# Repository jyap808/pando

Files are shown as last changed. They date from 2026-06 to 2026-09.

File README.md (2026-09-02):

# Pando Keyboard

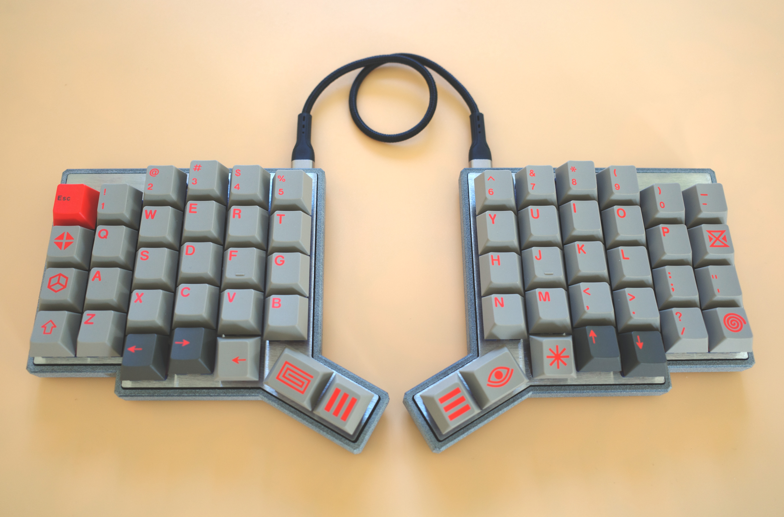
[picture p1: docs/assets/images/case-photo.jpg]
Pando case


Pando is a wired 58-key column-staggered split keyboard. It uses an integrated MCU design on the STM32 platform (STM32G0B1) with an IO expander (PCA9555) on the secondary half, connected over USB-C.

> [!NOTE]
> 📘 The **[Documentation pages](https://jyap808.github.io/pando)** contain a Build and Firmware guide.

> [!TIP]
> 🚀 Want one? Pre-assembled and PCB-tested kits are available on [Etsy](https://www.etsy.com/listing/4567044197/). Your support helps me keep this project open-source and encourages the development of new models!




## Features

- STM32G0B1KBT6 MCU (64 MHz Cortex-M0+, 144 KB SRAM)
- PCA9555 IO expander on the secondary half
- USB-C split communication with ESD protection on all ports
- Hotswap switch sockets
- Single-sided SMD components for hotplate soldering
- Vial firmware for keymap configuration
- Same key layout as the [Pando58](https://jyap808.github.io/pando58), but as an assembled PCB instead of a DIY kit

## Repository

| Directory | Description |
| --- | --- |
| `kicad/` | Schematics and PCB (left, right, switch plates) |
| `firmware/` | QMK/Vial keyboard definition |
| `ergogen/` | Layout configuration and case/plate generation |
| `case/` | 3D printed case models (FreeCAD) |
| `docs/` | This project's documentation site (built with [Zensical](https://zensical.org/)) |

## Firmware

Pando runs [Vial](https://get.vial.today/) firmware. Precompiled builds are on [GitHub Releases](https://github.com/jyap808/pando/releases) — flash with `dfu-util`, or build from source with the keyboard definition in `firmware/keyboards/`. See [Installing Firmware](https://jyap808.github.io/pando/firmware/installing-firmware/) for details.

## License

[Pando Keyboard](https://github.com/jyap808/pando) © 2026 by [Julian Yap](https://julianyap.com/) is Open Hardware, licensed under [CERN-OHL-S v2](https://ohwr.org/cern_ohl_s_v2.txt). See [LICENSE](LICENSE).

The firmware in `firmware/` is licensed under the [GPL v2](https://www.gnu.org/licenses/old-licenses/gpl-2.0.html).

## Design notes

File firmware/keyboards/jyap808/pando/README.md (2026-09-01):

# Pando

Split keyboard with STM32G0B1KBT6 master communicating with a PCA9555 I/O
expander slave over I2C via USB-C interconnect. Works as a full 58-key split,
or the left half can be used standalone.

## Matrix Configuration

The keyboard is a 58-key columnar split (mirroring the Pando58 layout) with a
single STM32G0B1 master driving both halves:

- **Left half**: rows B0-B2/A8-A9 and cols A7/A6/A2-A5 are scanned directly
  from the MCU GPIOs.
- **Right half**: rows and cols go through the PCA9555 over I2C. `MATRIX_ROWS`
  is 5, `MATRIX_COLS` is 12 (6 per side), with the right half occupying matrix
  cols 6-11.

See `config.h` for `MATRIX_ROW_PINS_L/R` and `MATRIX_COL_PINS_L/R`. The custom
matrix driver in `matrix.c` drives one row low at a time (GPIO on the left,
PCA9555 output on the right) and reads the columns, so both halves are scanned
without any split-transport logic.

### Standalone use

The **left half works standalone**: at init the driver probes the PCA9555 and
only touches the right half over I2C while it is present. If the expander is
disconnected mid-session, the right-half columns are cleared so no keys stick,
and the driver re-probes every 2 seconds for the right half to come back (see
`RIGHT_HALF_RETRY_MS` in `matrix.c`).

### Testing

Build and flash:
```
make jyap808/pando:vial
```

Connect with `qmk console` — the firmware initialises the PCA9555, reads its
pins to verify connectivity, and configures its ports in `matrix_init_custom()`.
Check the console output for device detection and error messages.

## I2C Configuration

The STM32G0B1 uses the I2Cv2 peripheral which requires explicit timing register
configuration via `I2C1_TIMINGR_*` defines in `config.h`.

The SCL frequency formula is:
```
f_SCL = f_I2CCLK / ((SCLL+1 + SCLH+1) * (PRESC+1))
```

### Clock source

The GENERIC_STM32_G0B1XB board config (used by QMK for STM32G0B1) sets the I2C1
clock source to PCLK (64MHz) via `STM32_I2C1SEL = STM32_I2C1SEL_PCLK`.

This keyboard does not need to override the clock source — PCLK = SYSCLK
= 64MHz.

### Timing values

QMK's ChibiOS I2C driver takes `I2C1_TIMINGR_*` defines from `config.h` and
falls back to built-in defaults (in `platforms/chibios/drivers/i2c_master.c`,
commented as "assuming a 72MHz clock") if they are not set. The values in
`config.h` are those same defaults, spelled out explicitly so the timing does
not depend on QMK's fallback values:

- `I2C1_TIMINGR_PRESC = 0`
- `I2C1_TIMINGR_SCLDEL = 7` (8 × 15.625ns = 125ns data setup, meets FM 100ns minimum)
- `I2C1_TIMINGR_SDADEL = 0`
- `I2C1_TIMINGR_SCLH = 38`
- `I2C1_TIMINGR_SCLL = 129`

At the 64MHz PCLK on this board this gives f_SCL = 64MHz / 169 ≈ 378kHz,
which is valid Fast-mode.

### Voltage notes

VBUS provides 5V to the slave side, with I2C lines pulled up to 5V
via 5kΩ resistors. PB6/PB7 are 5V tolerant (FTf) on STM32G0B1.

## License

This keyboard definition is licensed under the [GPL v2](https://www.gnu.org/licenses/old-licenses/gpl-2.0.html).

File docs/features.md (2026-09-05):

# Features

[Pando](https://github.com/jyap808/pando/) is Open Hardware, licensed under the [CERN-OHL-S v2](https://ohwr.org/cern_ohl_s_v2.txt).

- **MCU:** [STM32G0B1KBT6](https://www.st.com/en/microcontrollers-microprocessors/stm32g0b1kb.html). This is a newer MCU that offers benefits over an older, more commonly used MCU such as the STM32F072CBT6:
    - 64 MHz ARM Cortex-M0+ core, up from 48 MHz
    - 144 KB SRAM, up from 16 KB (~9x)
    - Consolidated single-supply core (VDD) with a modern power layout, reducing decoupling capacitors from 6 to 1
    - Streamlined LQFP-32 package instead of LQFP-48, keeping the same 7x7 mm body with a larger 0.875 mm pin pitch for easier soldering
    - Active ST support, keeping the design future-proof
- **IO expander:** PCA9555, communicating with the MCU over I²C
- **Split communication:** USB-C with ESD protection on all ports
- **Switches:** Hotswap sockets
- **Assembly:** Single-sided SMD components for hotplate soldering

The project uses [Ergogen](https://github.com/ergogen/ergogen) for layout generation and [KiCad](https://www.kicad.org/) for schematic/PCB design.

## Layout Template

Print out this [1:1 letter-size template](assets/pando-layout.pdf) and test the layout.

<iframe src="assets/pando-layout.pdf" width="100%" height="800px" style="border: 1px solid rgba(0,0,0,0.2); border-radius: 4px;"></iframe>

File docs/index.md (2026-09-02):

# Pando Keyboard

Pando case

Pando is a wired 58 key column-staggered split keyboard.

It uses an integrated MCU design on the STM32 platform with an IO expander on the secondary half of the keyboard.

Pando utilizes the same key layout as the [Pando58](https://jyap808.github.io/pando58). The core difference is that the Pando58 keyboard was designed as a DIY kit (with external controllers) while Pando is designed as an assembled PCB. This allows for a cleaner and more cohesive design.

!!! tip "Buy Pando"
    Pando comes as a pre-assembled kit on [Etsy](https://www.etsy.com/listing/4567044197/). Just provide your own keycaps and switches. Your support helps me keep this project open-source and encourages the development of new models!

## Getting Started

Visit the [Build page](build/) to learn about the assembly process.

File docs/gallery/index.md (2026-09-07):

# Gallery

Here are some examples to inspire your build.

A more extensive gallery of keycap options can be found in the [Pando58 Gallery](https://jyap808.github.io/pando58/gallery).

## MJF Case

Here is the Multi-Jet Fusion (MJF) printed case, printed in PA12-HP Nylon in natural grey. It features a stainless steel switch plate and bottom plate.

This MJF case suits my design ethos — simple, functional, minimal, true to its materials. Inspired by Brutalist architecture, MJF substitutes for concrete in its raw unfinished grey tone, with stainless steel peeking out from top and bottom.

Keycaps are Keykobo Signet. I prefer sets with icon modifiers since I flip the 3 inner thumb keys upside-down for a more natural feel. For backspace, I use a flipped right arrow key.

MJF Case - Top view with USB-C interconnect cable

Top view with USB-C interconnect cable.

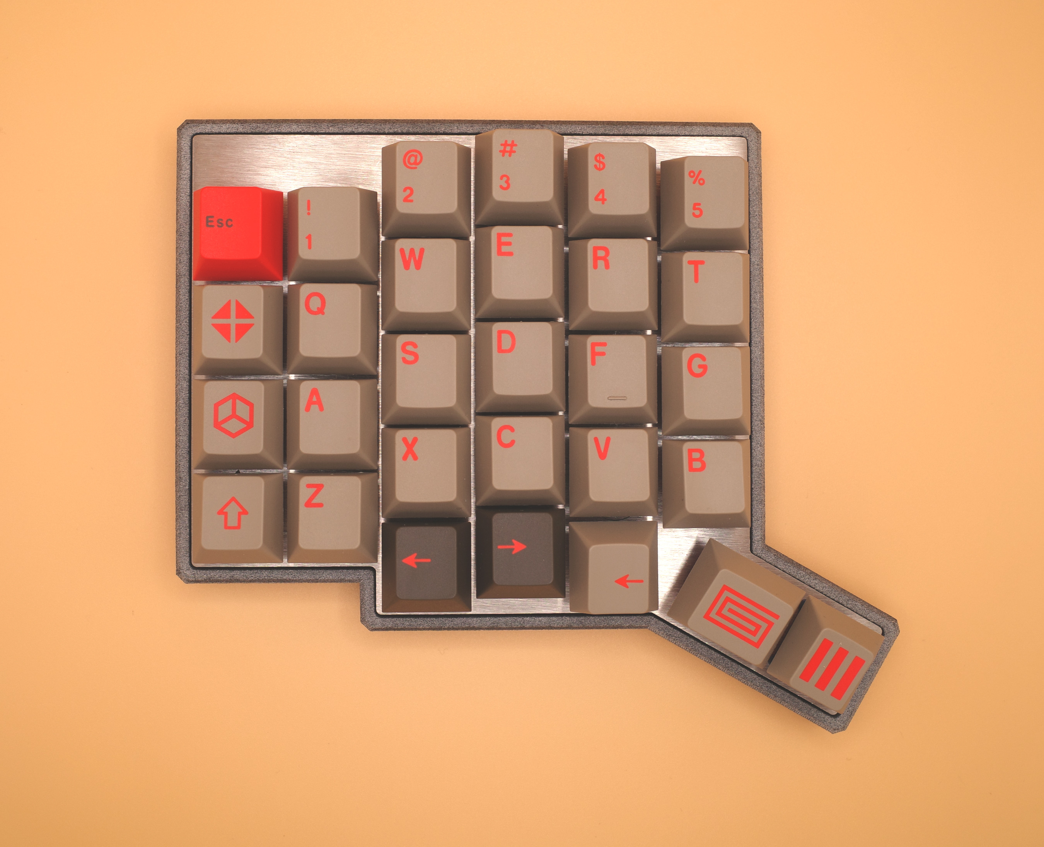
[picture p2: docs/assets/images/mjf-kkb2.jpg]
MJF Case - Left half top view


Left half top view.

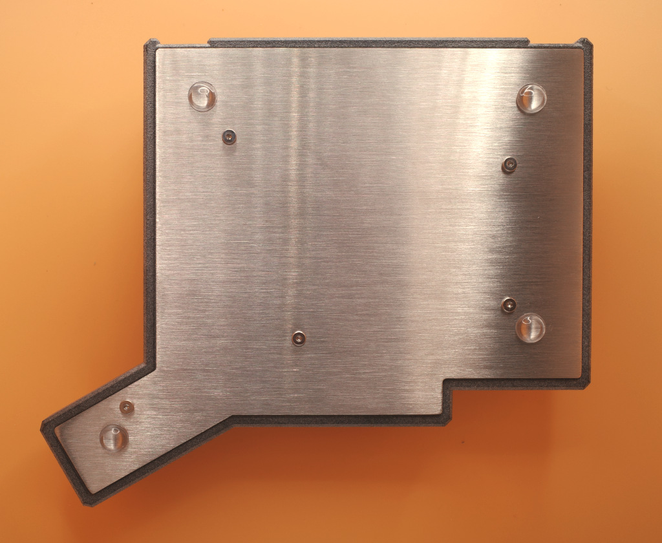
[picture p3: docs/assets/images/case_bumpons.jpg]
MJF Case - Left half, bottom view with the stainless steel plate


Left half, bottom view with the stainless steel plate.

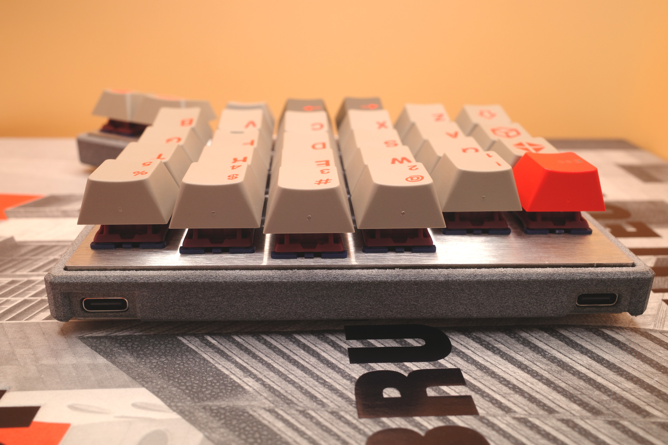
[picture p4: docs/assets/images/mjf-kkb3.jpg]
MJF Case - Left half, view from the back


Left half, view from the back.

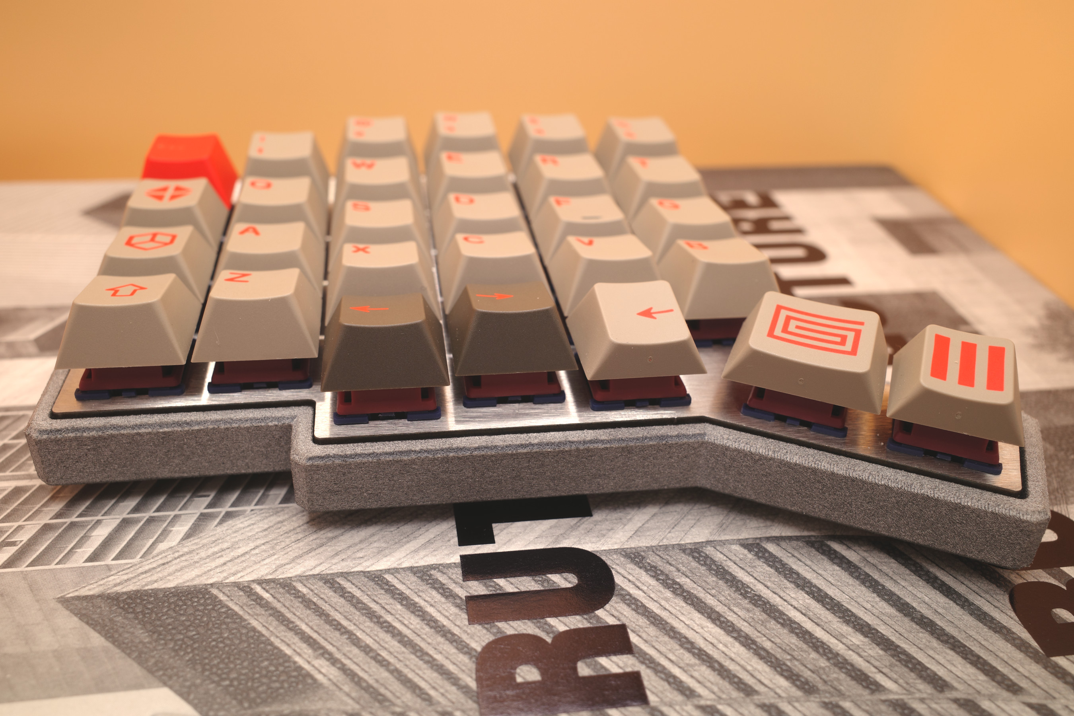
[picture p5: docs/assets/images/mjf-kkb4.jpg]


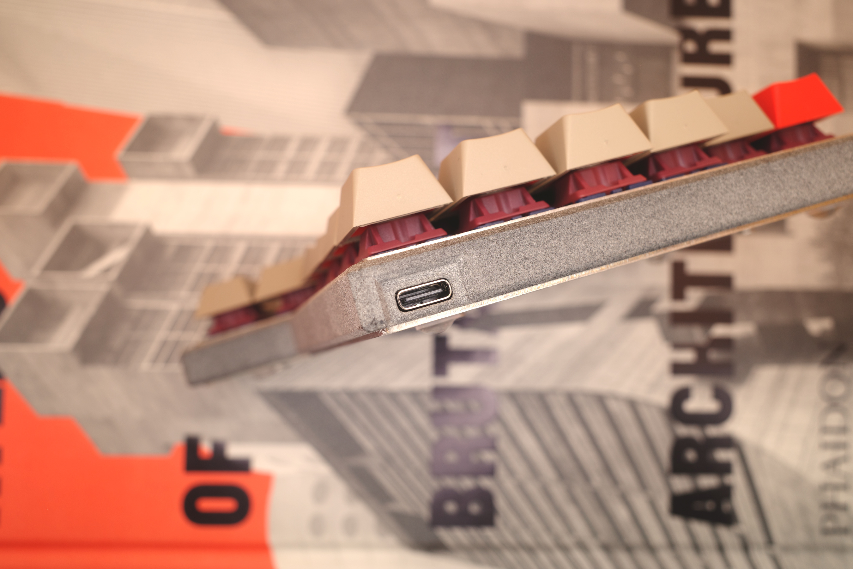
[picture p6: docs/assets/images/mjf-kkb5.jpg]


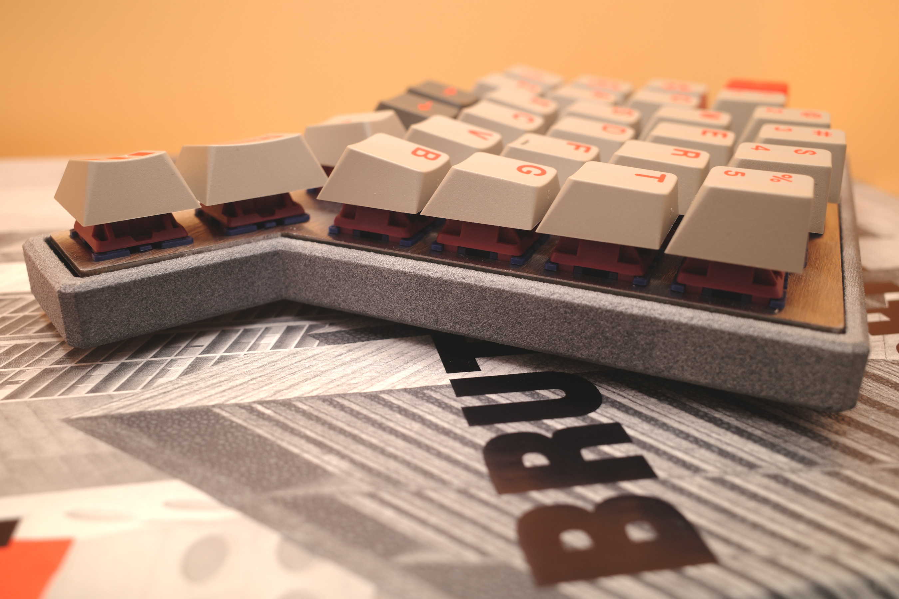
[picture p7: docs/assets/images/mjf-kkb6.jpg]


## 3D Printed Case

Here is the 3D printed case, printed in black Ambrosia ASA filament. It features a FR4 switch plate in black. Keycaps are GMK Dots. I am a fan of keycap sets where the modifiers are minimal icons.

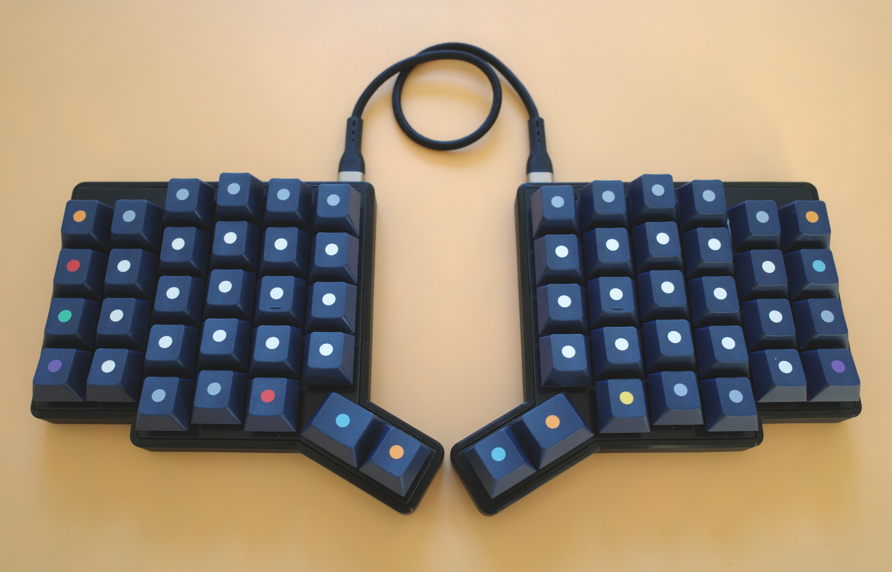
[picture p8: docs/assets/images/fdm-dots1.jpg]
3D Printed Case - Top view with USB-C interconnect cable


Top view with USB-C interconnect cable.

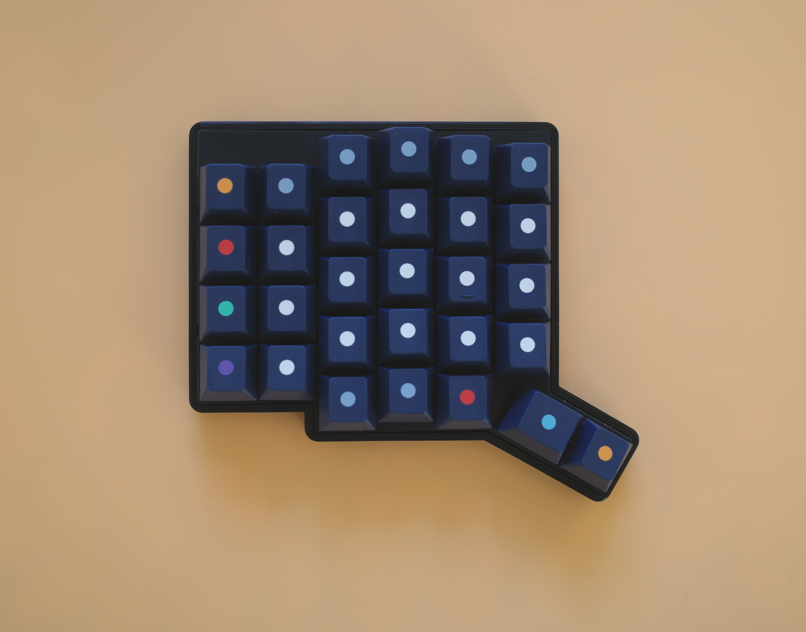
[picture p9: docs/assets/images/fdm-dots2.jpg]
3D Printed Case - Left half top view


Left half top view.

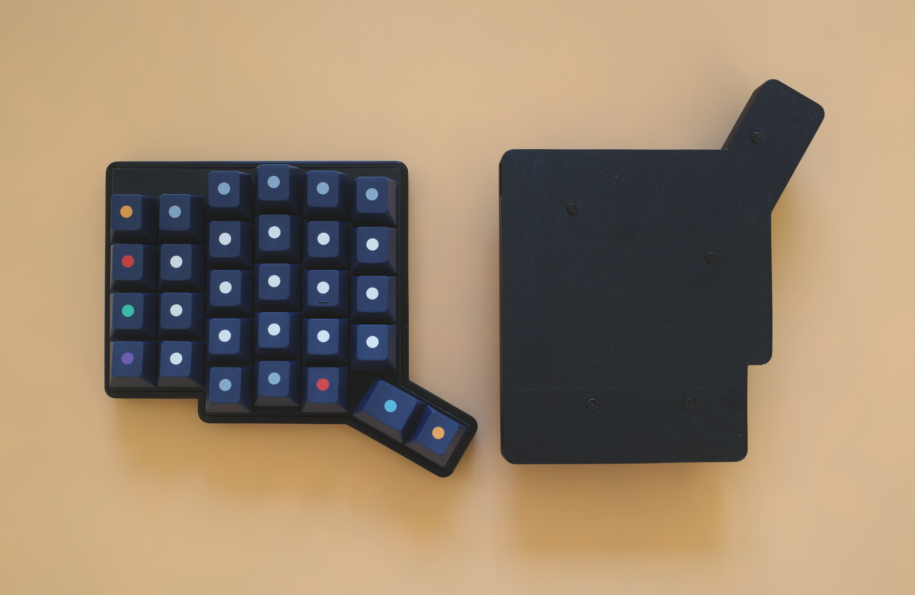
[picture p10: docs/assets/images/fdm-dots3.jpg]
3D Printed Case - Left half top view and right half bottom view


Left half top view and right half bottom view.

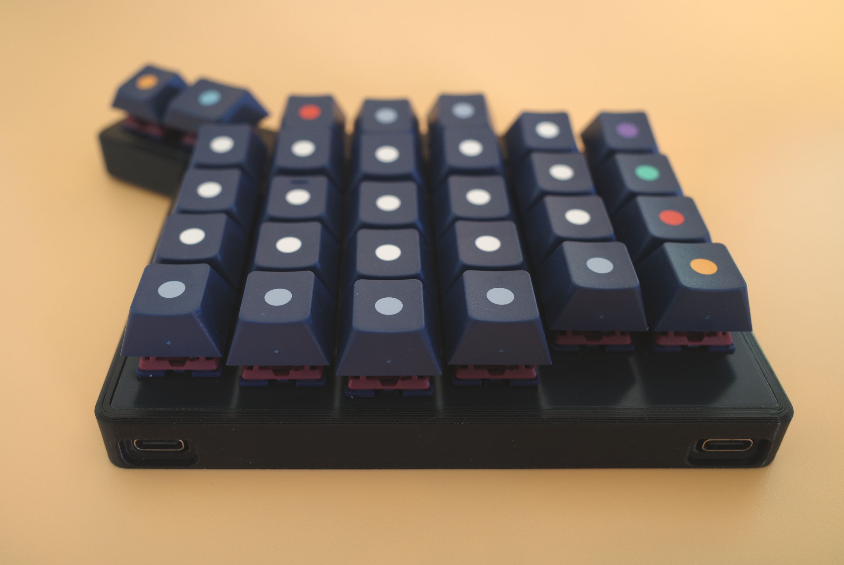
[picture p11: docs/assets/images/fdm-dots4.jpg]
3D Printed Case - Left half, view from the back


Left half, view from the back.

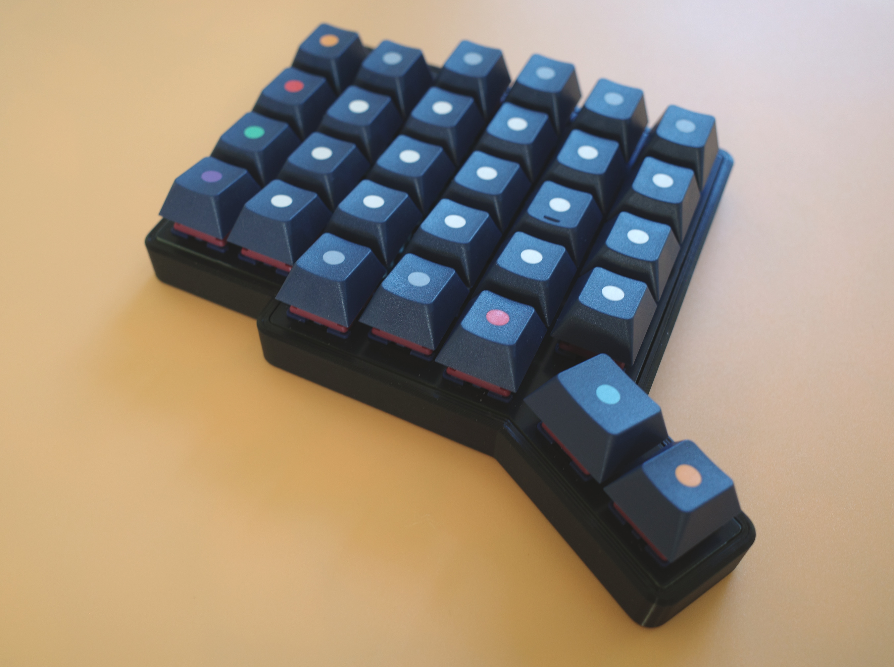
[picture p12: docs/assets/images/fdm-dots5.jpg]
3D Printed Case - Left half, angled view


Left half, angled view.

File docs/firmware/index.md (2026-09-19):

# Firmware and Configuration

Pando uses Vial firmware. Once installed, [Vial](https://get.vial.today/) (the application) is used to configure the keyboard.

!!! note
    Pre-built keyboards from my [Etsy Store](https://www.etsy.com/listing/4567044197/) arrive pre-flashed with firmware and fully PCB-tested, ready to use out of the box.

To flash the keyboard yourself, see [Installing Firmware](installing-firmware.md).

## Getting Vial

Download Vial (the desktop application) from the [official website](https://get.vial.today/) for your platform.

Alternatively, you can use [Vial Web](https://vial.rocks) in your browser — no download required.

## Configuring with Vial

Open [Vial](https://get.vial.today/) to configure the keyboard. The Pando should connect automatically when the firmware is installed.

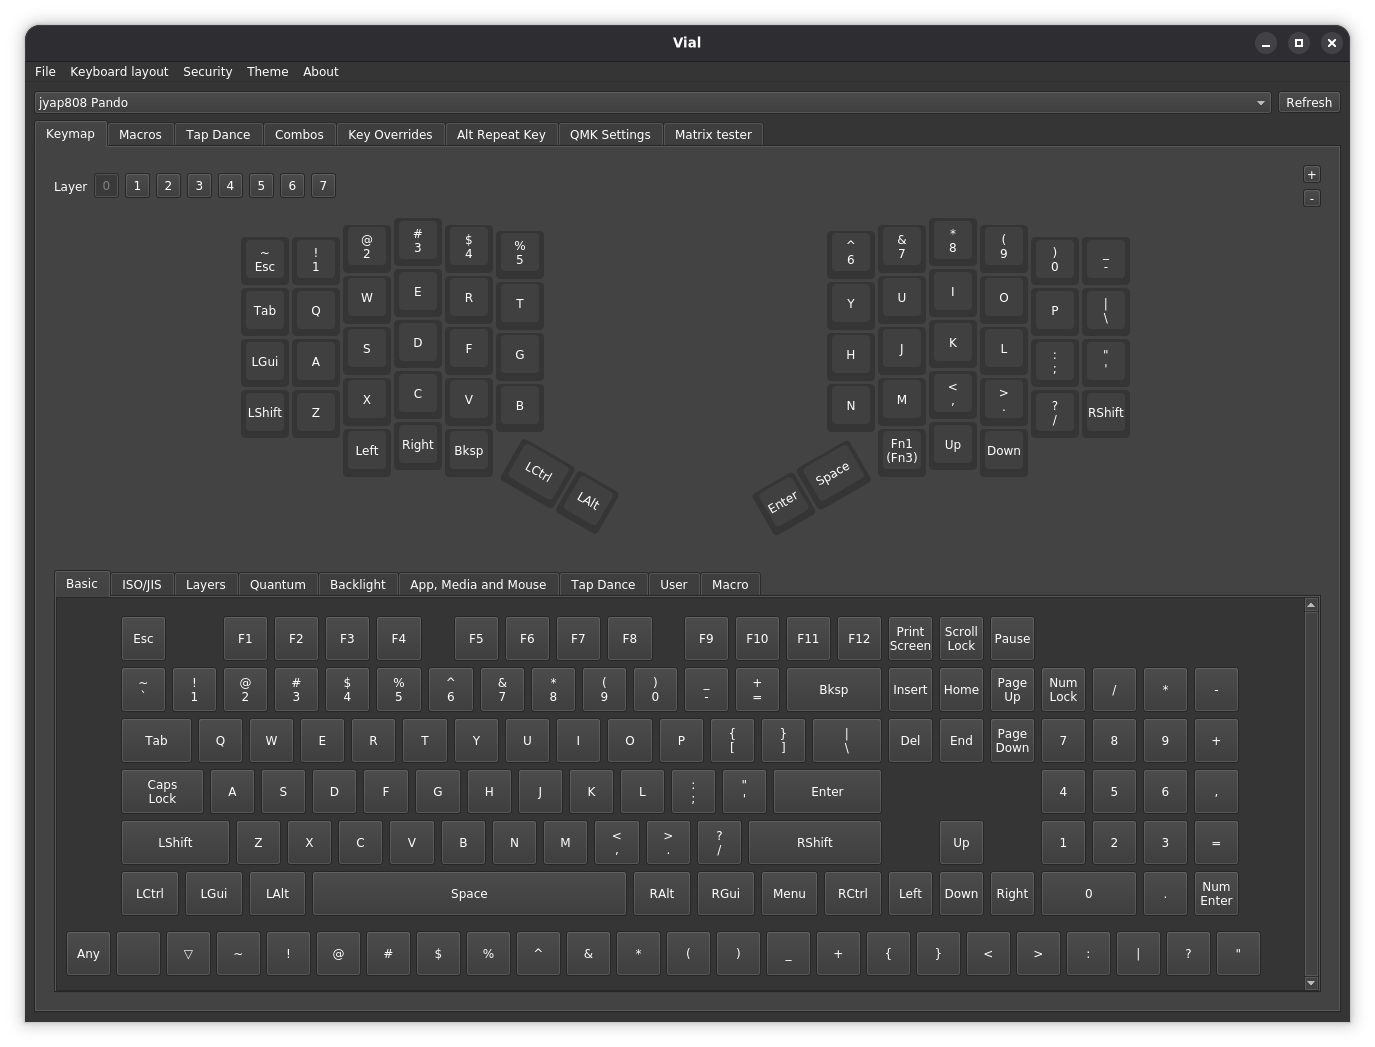
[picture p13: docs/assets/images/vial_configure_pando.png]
Vial application showing Pando keyboard configuration


Vial allows you to remap keys, create layers, and configure macros for your Pando keyboard.

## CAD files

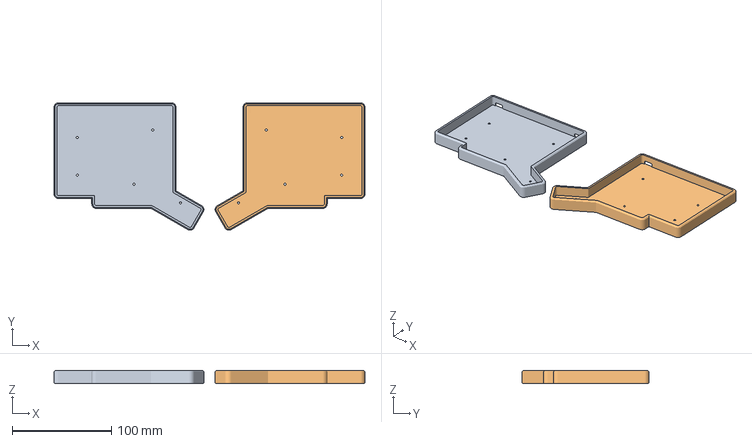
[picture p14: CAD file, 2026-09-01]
case/PandoCase.FCStd
313.1 x 128.3 x 12.6 mm
Pando FDM Left (Meshed)
Pando FDM Right (Meshed)

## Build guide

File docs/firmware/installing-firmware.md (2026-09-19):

# Installing Firmware

!!! note
    Pando is a split keyboard with an MCU on the master half only. The secondary half uses an I/O expander over I2C, so only the master MCU needs to be flashed.

There are two ways to get the latest Vial firmware for Pando:

1. **Precompiled firmware** — Download precompiled firmware from [GitHub Releases](https://github.com/jyap808/pando/releases) and flash via `dfu-util` (simplest option).
2. **Manual build method** — Clone the vial-qmk repo, build locally, and flash via CLI.

## Prerequisites: Enable the Boot Button (Legacy Boot Mode)

!!! note
    This step is not required for pre-built keyboards from my [Etsy Store](https://www.etsy.com/listing/4567044197/) as it has already been completed.

The STM32G0 series handles booting differently from older STM32 parts. Booting is controlled by a software configuration bit called `nBOOT_SEL` in the Option Bytes rather than purely by hardware.

By default, `nBOOT_SEL` is set to `1`, which tells the MCU to **ignore the physical BOOT0 pin** entirely. Instead it uses an **Empty Check** mechanism: a blank chip automatically enters DFU mode, but once code is flashed, it always boots straight into your firmware — ignoring BOOT0 even if it's held HIGH.

### Why?

The BOOT0 pin on the G0 is multiplexed with GPIOs and programming lines (e.g. SWCLK on PA14). Disabling it by default lets designers use that pin as a regular I/O without risking accidental bootloader entry.

### Enabling Legacy Boot Behavior

To restore hardware BOOT0 control (so a physical button can force DFU mode at any time), clear the `nBOOT_SEL` bit. This can be done via the GUI or the CLI, both using the [STM32CubeProgrammer](https://www.st.com/en/development-tools/stm32cubeprog.html) tool.

**GUI method:** Open STM32CubeProgrammer → Option Bytes → User Configuration, uncheck `nBOOT_SEL`, and apply.

**CLI method:** Use `STM32_Programmer_CLI` to list devices, display option bytes, and set the bit.

First, list available DFU devices:

    $ STM32_Programmer_CLI -l

    =====  DFU Interface   =====

    Total number of available STM32 device in DFU mode: 1

      Device Index           : USB1
      Product ID             : DFU in FS Mode
      Device ID              : 0x0467

Display current option bytes (factory default shows `nBOOT_SEL : 0x1`):

    $ STM32_Programmer_CLI -c port=usb1 -ob displ

      User Configuration:

         nBOOT_SEL    : 0x1 (BOOT0 signal is defined by nBOOT0 option bit)

Clear `nBOOT_SEL` to enable legacy boot pin behavior:

    $ STM32_Programmer_CLI -c port=usb1 -ob nBOOT_SEL=0

    OPTION BYTE PROGRAMMING VERIFICATION:

    Option Bytes successfully programmed

Confirm the change (`nBOOT_SEL` now shows `0x0`):

    $ STM32_Programmer_CLI -c port=usb1 -ob displ

      User Configuration:

         nBOOT_SEL    : 0x0 (BOOT0 signal is defined by BOOT0 pin value (legacy mode))

### Recommended Setup Sequence

Clear the option byte on a fresh chip **before** flashing firmware. This ensures the BOOT0 pin is active even if your first firmware build has a catastrophic bug, guaranteeing you can always recover via DFU:

**Brand New MCU** → **Clear nBOOT_SEL** → **Test Bootloader** → **Flash Firmware**

## Precompiled Method: Download from Releases + `dfu-util`

1. Go to the [Releases page](https://github.com/jyap808/pando/releases)

2. Download the latest firmware file (e.g. `jyap808_pando_vial.bin`)

3. Put the keyboard into DFU mode by holding the boot/reset button on the MCU while plugging in the USBC cable.

4. Flash the firmware with `dfu-util`:

        dfu-util -d 0483:df11 -a 0 -s 0x08000000:leave -D jyap808_pando_vial.bin

    The device should show up as an STM32 BOOTLOADER. On Linux you may need `sudo` or a udev rule for the DFU device.

    A quick breakdown of the `dfu-util` flags:

    - `-d 0483:df11` — the USB VID:PID of ST's STM32 bootloader, which all STM32-system-DFU devices enumerate as.
    - `-a 0` — select alternate 0, the internal flash media. This is the same alternate QMK uses when flashing `stm32-dfu` boards.
    - `-s 0x08000000:leave` — program at `0x08000000`, the standard STM32G0 flash base address, then `leave` to jump to the application on completion.

5. The keyboard will reboot with the new firmware

## Manual Build Method: CLI Build + Flash (Advanced)

1. Clone the official Vial QMK fork:

        git clone https://github.com/vial-kb/vial-qmk.git
        cd vial-qmk

2. Initialize submodules (important for QMK dependencies):

        make git-submodule

3. Clone or download the Pando keyboard folder from the [GitHub repo](https://github.com/jyap808/pando).

    Copy the entire `firmware/keyboards/jyap808/pando/` folder into `vial-qmk/keyboards/jyap808/pando/`.

4. Compile the Vial firmware:

        make jyap808/pando:vial

5. Flash using the CLI.

    For an STM32 target this uses USB DFU. You can use QMK's wrapper, which runs `dfu-util` under the hood:

        qmk flash jyap808/pando:vial

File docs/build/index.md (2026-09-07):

# Assembly

## Overview

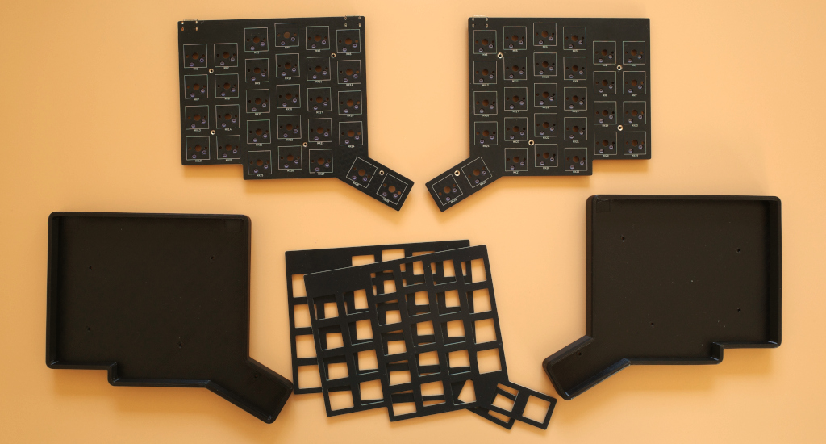
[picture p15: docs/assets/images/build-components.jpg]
Build components


This guide covers the **3D-printed case** build using the 2 PCBs, 2 reversible switch plates and 2 3D-printed cases.

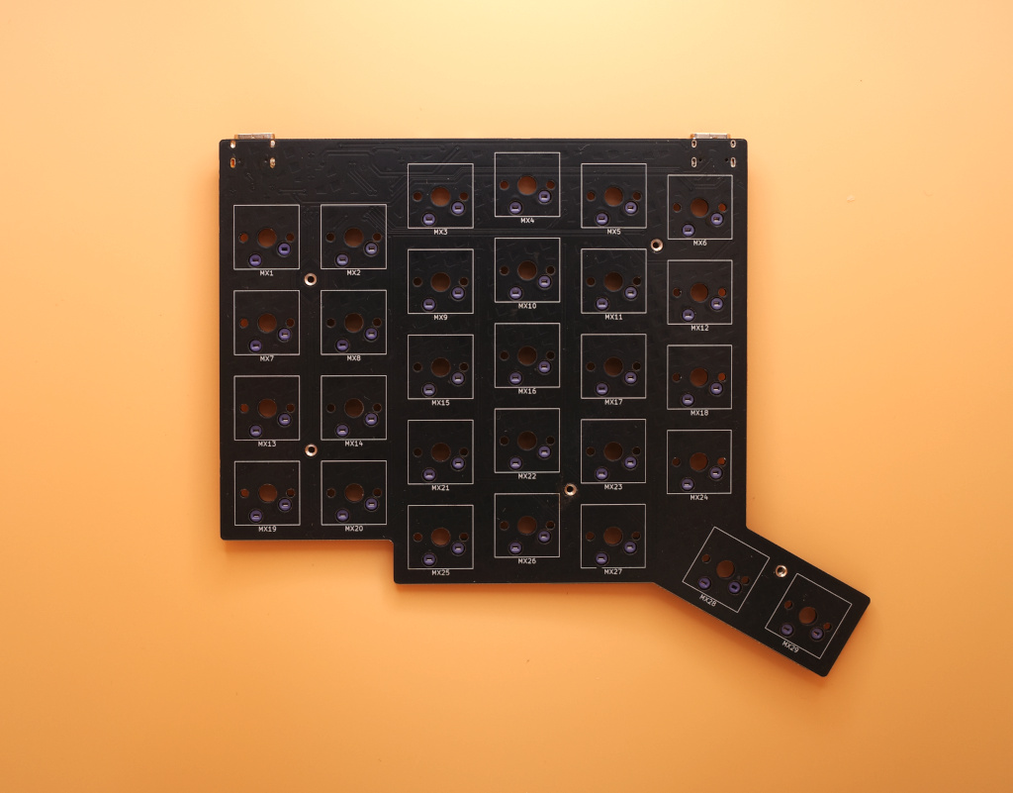
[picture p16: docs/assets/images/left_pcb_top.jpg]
Left PCB top


This guide walks through assembling **one half** (the Left half) of the PCBs since the assembly is identical on both halves. Pictured above is the Left PCB top side.

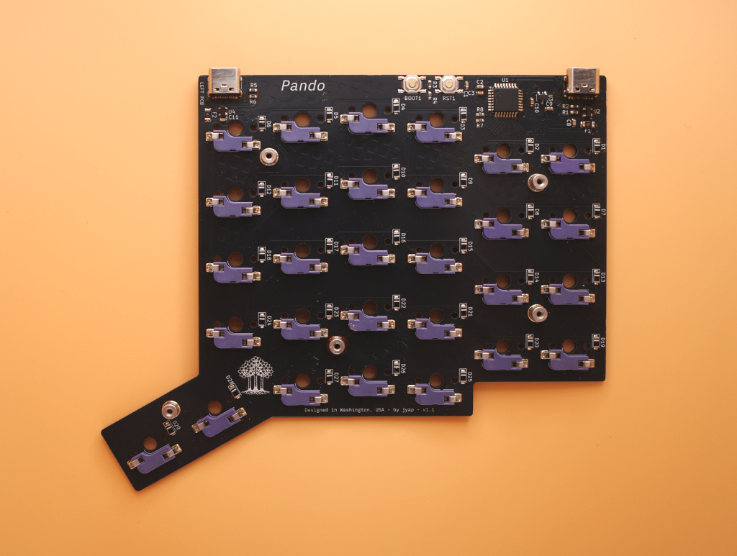
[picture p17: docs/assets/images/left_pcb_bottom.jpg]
Left PCB bottom


Left PCB bottom side, ready to be assembled. The Left PCB has more components and 2 USB-C ports. In the top left, you can see it says "Left PCB". In this view, the top Left USB-C port is the interconnect port (connects to the Right side PCB) and the Right USB-C port is the main port which connects to the PC.

## Assembly Steps

### Switches - Switch and Plate Installation

The switches are installed between the switch plate and the PCB.

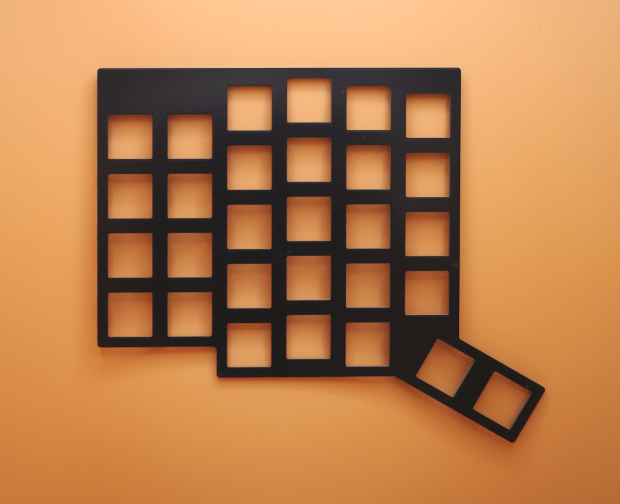
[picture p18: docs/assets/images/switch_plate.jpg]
Switch plate


The switch plate is reversible and works for both Left and Right halves.

#### Installing Switches on the Plate

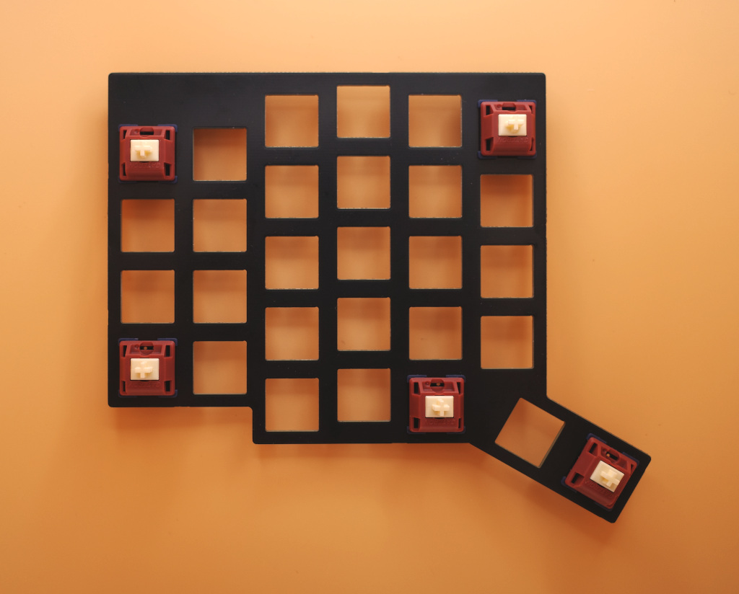
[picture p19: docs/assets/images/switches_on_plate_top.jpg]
Switches on Plate - Top


Insert guide switches into the plate. These are initial switches used to align the plate with the PCB before inserting the rest of the switches.

Place switches on the edges for structural support. Use the same 5 positions pictured.

The switch pins must face **down** (towards the bottom of the plate) to align with the hotswap sockets.

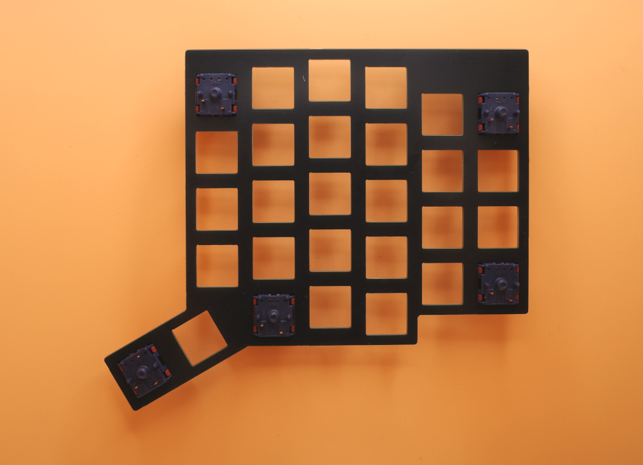
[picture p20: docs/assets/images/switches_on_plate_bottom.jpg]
Switches on Plate - Bottom


#### Attaching Switches to PCB

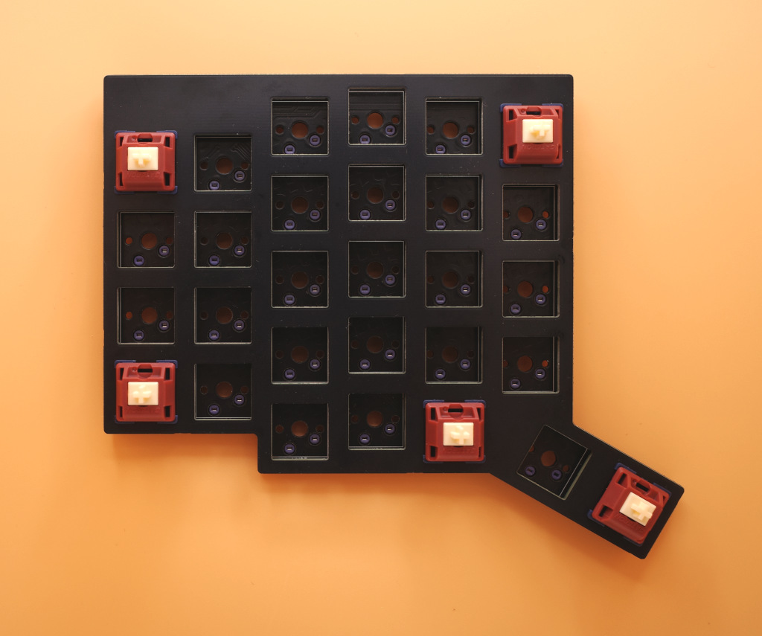
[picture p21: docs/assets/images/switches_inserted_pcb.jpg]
Switches Inserted into PCB


Place the switch plate onto the PCB. Fully press the switches into the hotswap sockets. When inserting the switches, press on the back of the socket to prevent excess pressure on it from the pins.

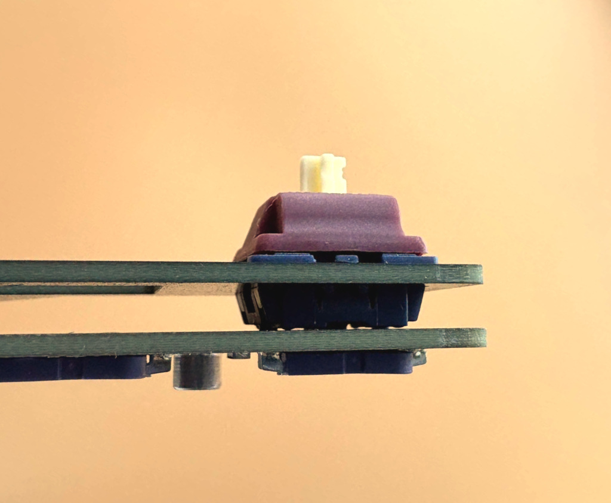
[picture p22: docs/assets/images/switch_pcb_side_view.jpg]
Switch PCB Side View


The image above shows a switch sitting flush against the PCB.

Insert the remaining switches into the PCB.

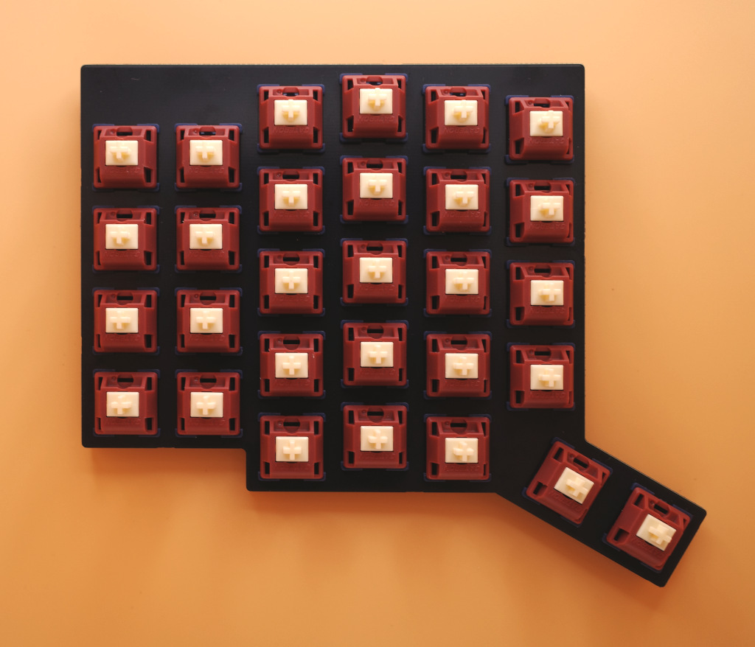
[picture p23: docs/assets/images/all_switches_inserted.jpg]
All Switches Inserted


The above image shows all 29 switches inserted into the plate for one half of the keyboard.

### Case

#### Insert PCB into Case

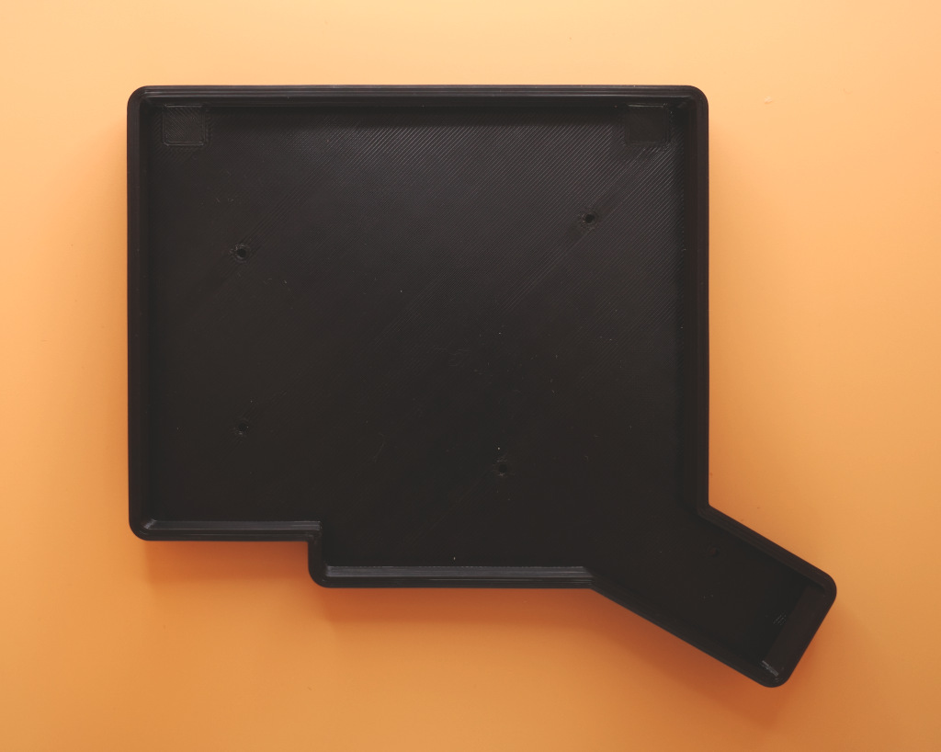
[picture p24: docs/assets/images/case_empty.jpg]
Empty case


The USB-C ports on the PCB must slot into the back of the case first! The Left half has 2 USB-C ports and the Right half has 1 USB-C port.

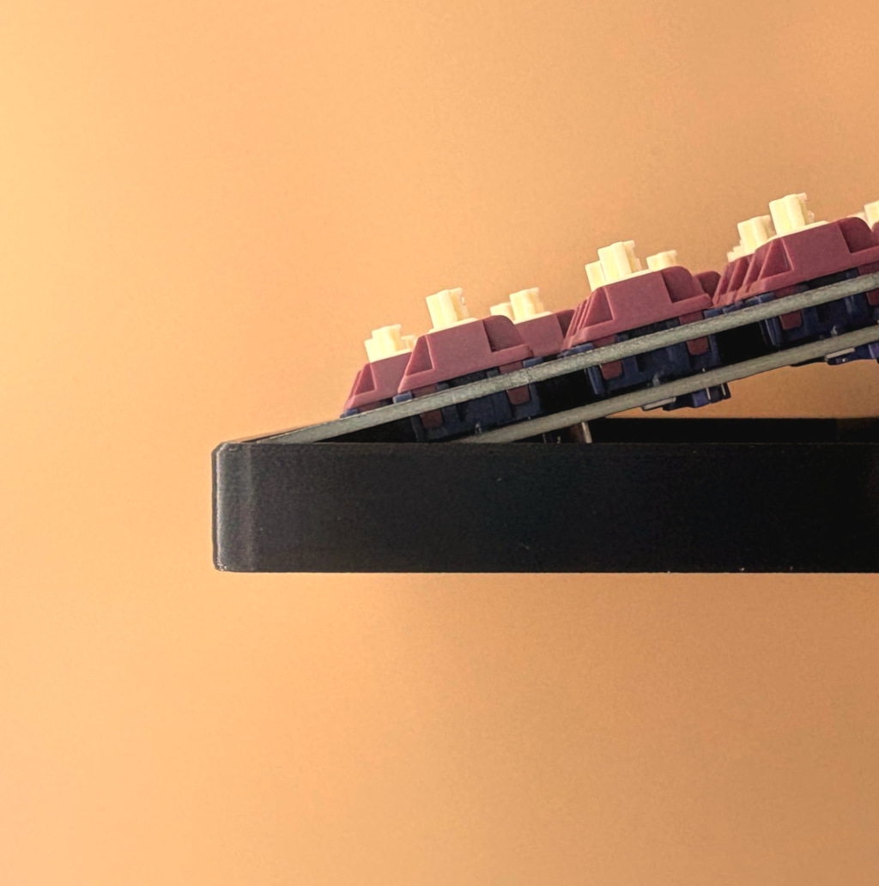
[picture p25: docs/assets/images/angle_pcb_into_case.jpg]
Angle PCB into case


Angle the PCB and populated switch plate downwards and into the case so that the USB-C ports slide into the case openings.

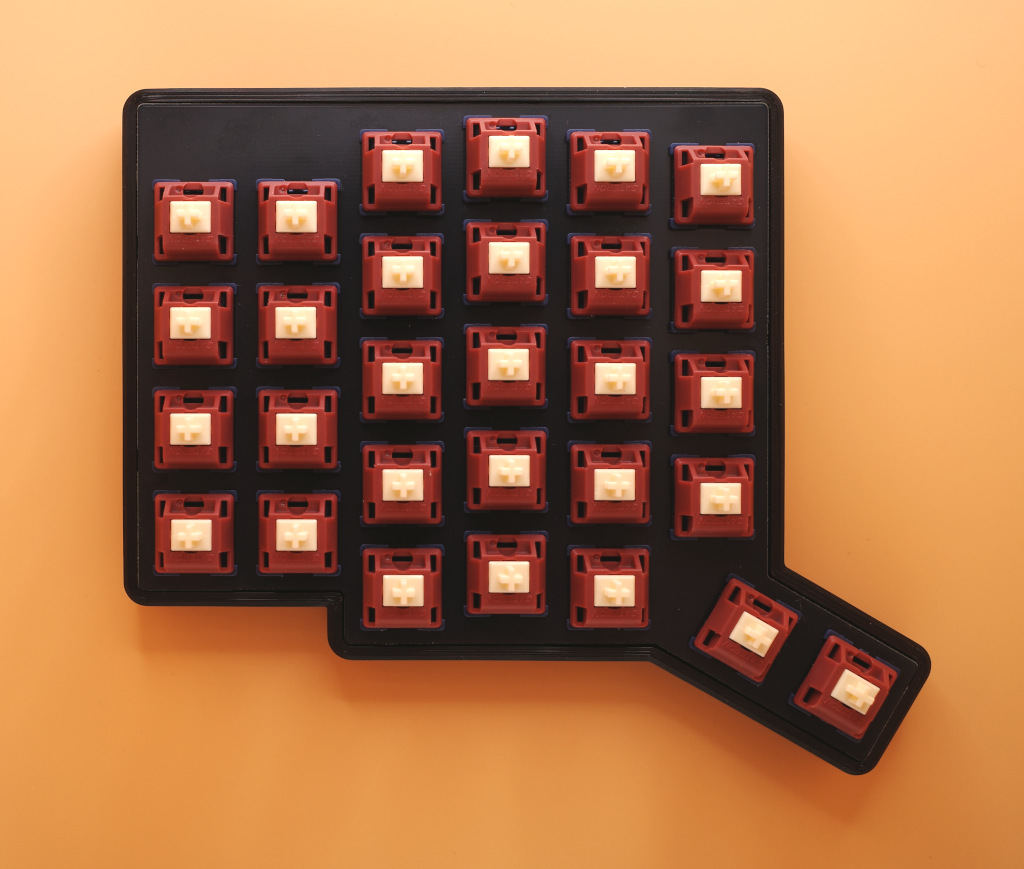
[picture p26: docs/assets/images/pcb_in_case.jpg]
PCB in case


The front side can then slot into the case. When disassembling, reverse this and take the front out first.

#### Screw the PCB into the Case

Screw the 5 screws into the case on the bottom.

Do not over-tighten the screws as you don't want to damage the standoffs attached to the PCB.

### Keycaps and Optional Bumpons

#### Keycaps

Add keycaps to the switches.

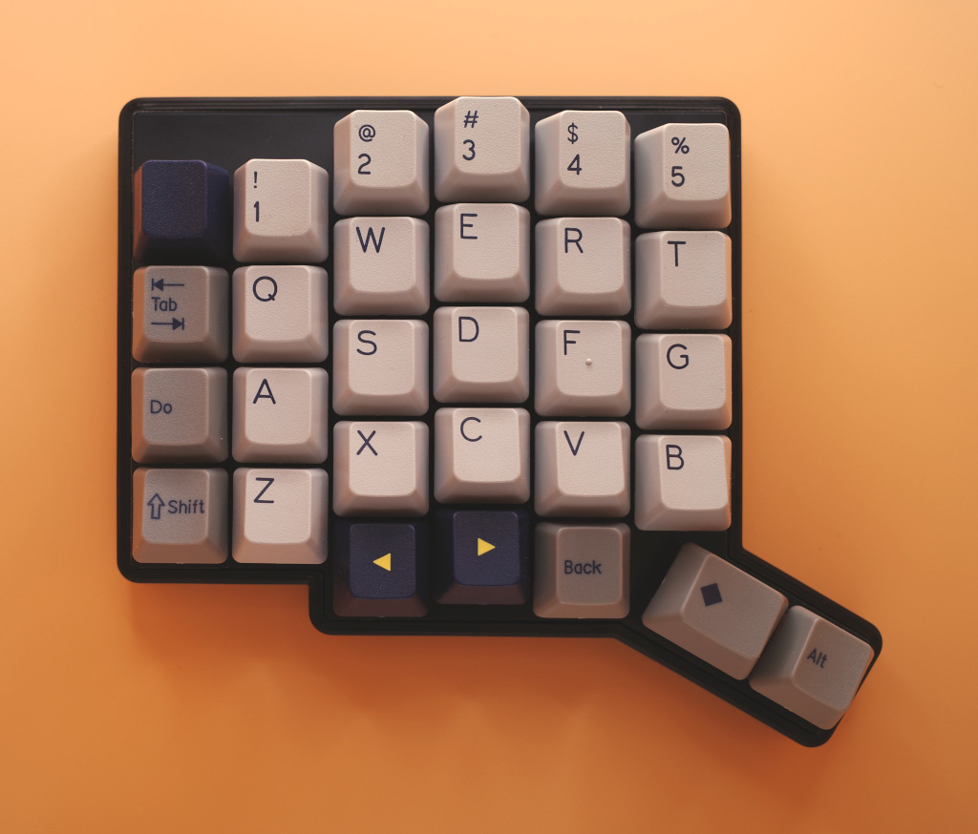
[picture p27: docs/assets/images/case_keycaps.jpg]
Case with keycaps


You can add keycaps to suit the layout that you deem optimal. This may come through some experimentation with layouts that you can configure through [Vial](../firmware/).

One of the thumb keys is designed to take a 1.25U key but you can also use a 1U key.

More Pando build examples can be found in the [Gallery](../gallery/).

A more extensive gallery of keycap options can be found in the [Pando58 Gallery](https://jyap808.github.io/pando58/gallery).

#### Bumpons

Optionally add the Bumpons to the bottom of the case.

Case with bumpons

Add 4 Bumpons per side in the configuration shown.

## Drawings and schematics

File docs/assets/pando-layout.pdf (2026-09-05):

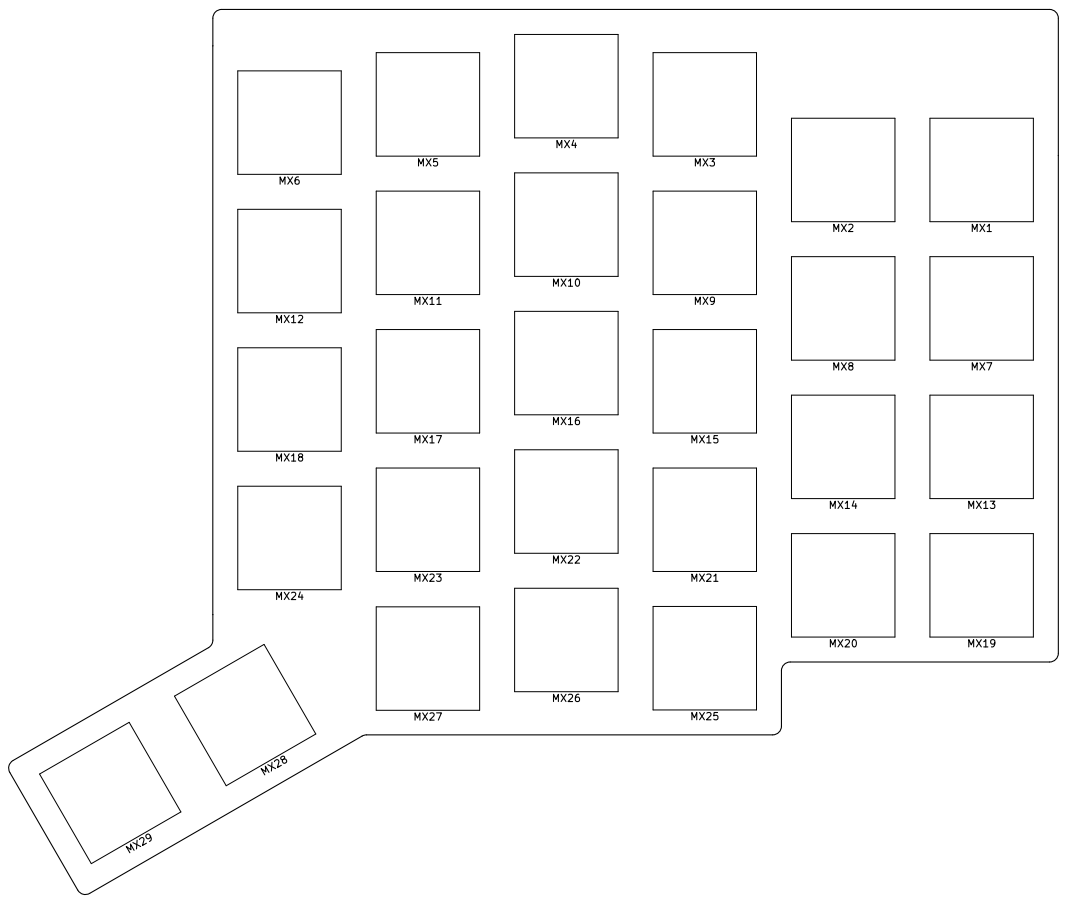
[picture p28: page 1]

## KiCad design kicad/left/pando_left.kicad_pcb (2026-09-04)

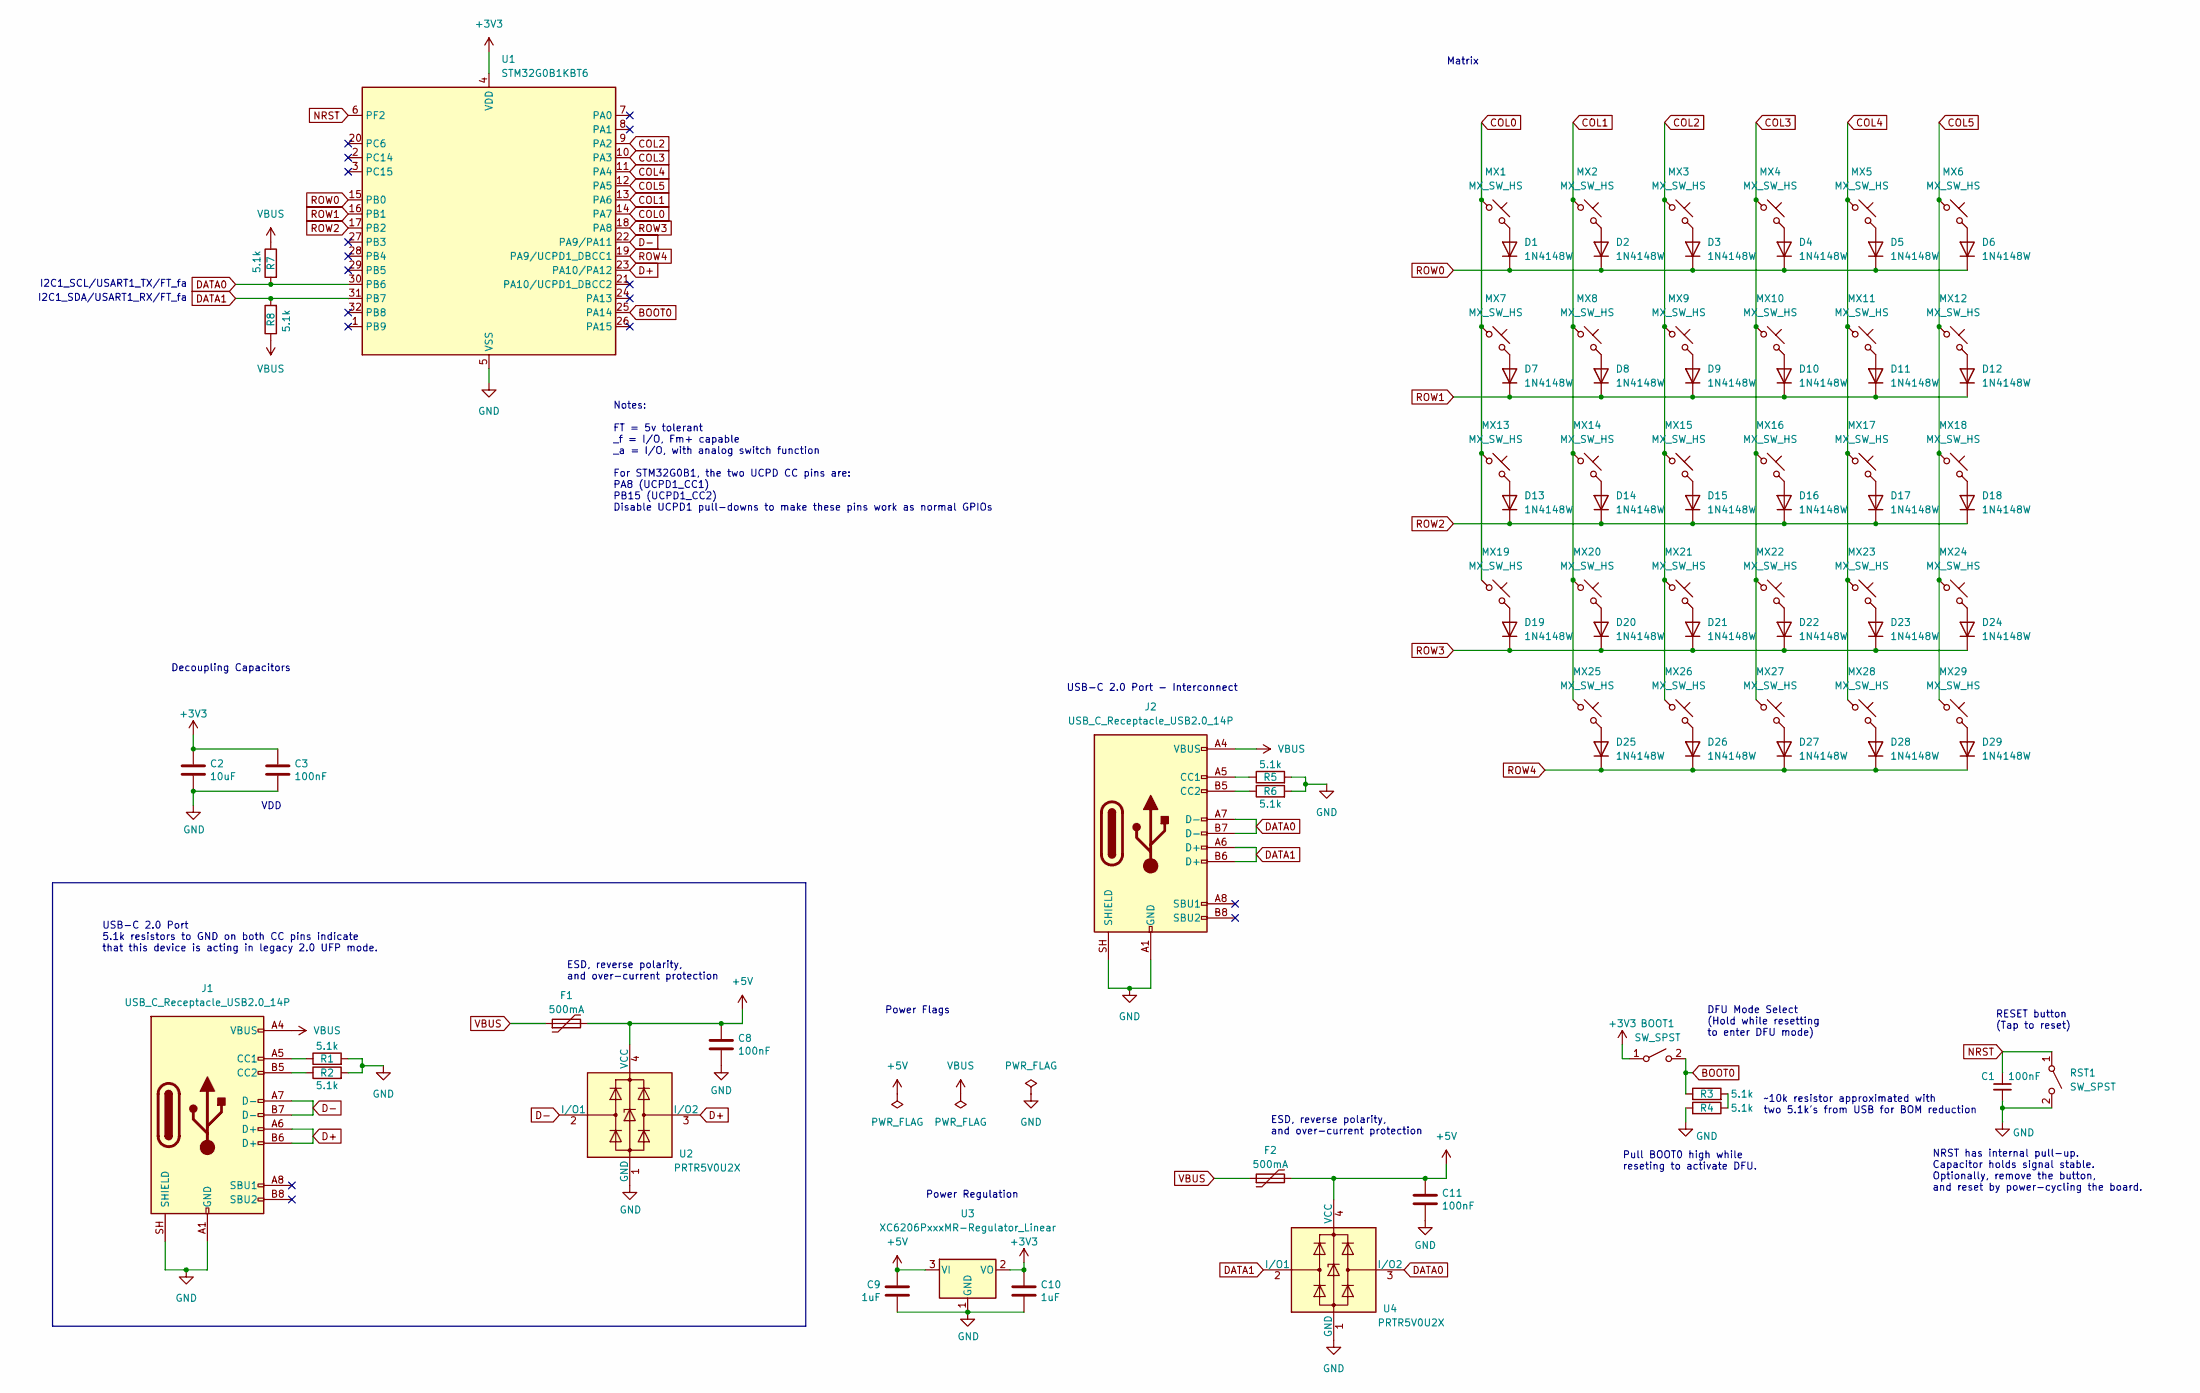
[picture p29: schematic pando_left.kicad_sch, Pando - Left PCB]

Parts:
BOOT1: SW_SPST; SW_SPST_TL3342; LCSC C318884
C1, C3, C8, C11: 100nF; C_0603_1608Metric; LCSC C14663
C2: 10uF; C_0603_1608Metric; LCSC C19702
C9, C10: 1uF; C_0603_1608Metric; LCSC C15849
D1, D2, D3, D4, D5, D6, D7, D8, D9, D10, D11, D12, D13, D14, D15, D16, D17, D18, D19, D20, D21, D22, D23, D24, D25, D26, D27, D28, D29: 1N4148W; D_SOD-123; LCSC C81598
F1, F2: 500mA; Fuse_1206_3216Metric; LCSC C135341
J1, J2: USB_C_Receptacle_USB2.0_14P; USB_C_Receptacle_HRO_TYPE-C-31-M-12; LCSC C165948
MX1, MX2, MX3, MX4, MX5, MX6, MX7, MX8, MX9, MX10, MX11, MX12, MX13, MX14, MX15, MX16, MX17, MX18, MX19, MX20, MX21, MX22, MX23, MX24, MX25, MX26, MX27, MX28, MX29: MX_SW_HS; SW_Hotswap_Kailh_MX; LCSC C41430893
R1, R2, R3, R4, R5, R6, R7, R8: 5.1k; R_0603_1608Metric; LCSC C2907114
RST1: SW_SPST; SW_SPST_TL3342; LCSC C318884
U1: STM32G0B1KBT6; LQFP-32_7x7mm_P0.8mm
U2, U4: PRTR5V0U2X; SOT-143; LCSC C2827688
U3: XC6206PxxxMR-Regulator_Linear; SOT-23-3; LCSC C5446

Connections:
+3V3: BOOT1.1 (A), C2.1, C3.1, C10.1, U1.4 (VDD), U3.2 (VO)
+5V: C8.1, C9.1, C11.1, F1.2, F2.2, U2.4 (VCC), U3.3 (VI), U4.4 (VCC)
BOOT0: BOOT1.2 (B), R3.1, U1.25 (PA14)
COL0: MX1.1, MX7.1, MX13.1, MX19.1, U1.14 (PA7)
COL1: MX2.1, MX8.1, MX14.1, MX20.1, MX25.1, U1.13 (PA6)
COL2: MX3.1, MX9.1, MX15.1, MX21.1, MX26.1, U1.9 (PA2)
COL3: MX4.1, MX10.1, MX16.1, MX22.1, MX27.1, U1.10 (PA3)
COL4: MX5.1, MX11.1, MX17.1, MX23.1, MX28.1, U1.11 (PA4)
COL5: MX6.1, MX12.1, MX18.1, MX24.1, MX29.1, U1.12 (PA5)
D+: J1.A6 (D+), J1.B6 (D+), U1.23 (PA10/PA12), U2.3 (I/O2)
D-: J1.A7 (D-), J1.B7 (D-), U1.22 (PA9/PA11), U2.2 (I/O1)
DATA0: J2.A7 (D-), J2.B7 (D-), R7.2, U1.30 (PB6), U4.3 (I/O2)
DATA1: J2.A6 (D+), J2.B6 (D+), R8.2, U1.31 (PB7), U4.2 (I/O1)
GND: C1.2, C2.2, C3.2, C8.2, C9.2, C10.2, C11.2, J1.A1 (GND), J1.A12 (GND), J1.B1 (GND), J1.B12 (GND), J1.SH (SHIELD), J2.A1 (GND), J2.A12 (GND), J2.B1 (GND), J2.B12 (GND), J2.SH (SHIELD), R1.2, R2.2, R4.2, R5.2, R6.2, RST1.2 (B), U1.5 (VSS), U2.1 (GND), U3.1 (GND), U4.1 (GND)
NRST: C1.1, RST1.1 (A), U1.6 (PF2)
unnamed: D1.2 (A), MX1.2
unnamed: D2.2 (A), MX2.2
unnamed: D3.2 (A), MX3.2
unnamed: D4.2 (A), MX4.2
unnamed: D5.2 (A), MX5.2
unnamed: D6.2 (A), MX6.2
unnamed: D7.2 (A), MX7.2
unnamed: D8.2 (A), MX8.2
unnamed: D9.2 (A), MX9.2
unnamed: D10.2 (A), MX10.2
unnamed: D11.2 (A), MX11.2
unnamed: D12.2 (A), MX12.2
unnamed: D13.2 (A), MX13.2
unnamed: D14.2 (A), MX14.2
unnamed: D15.2 (A), MX15.2
unnamed: D16.2 (A), MX16.2
unnamed: D17.2 (A), MX17.2
unnamed: D18.2 (A), MX18.2
unnamed: D19.2 (A), MX19.2
unnamed: D20.2 (A), MX20.2
unnamed: D21.2 (A), MX21.2
unnamed: D22.2 (A), MX22.2
unnamed: D23.2 (A), MX23.2
unnamed: D24.2 (A), MX24.2
unnamed: D25.2 (A), MX25.2
unnamed: D26.2 (A), MX26.2
unnamed: D27.2 (A), MX27.2
unnamed: D28.2 (A), MX28.2
unnamed: D29.2 (A), MX29.2
unnamed: J1.A5 (CC1), R1.1
unnamed: J1.B5 (CC2), R2.1
unnamed: J2.A5 (CC1), R5.1
unnamed: J2.B5 (CC2), R6.1
unnamed: R3.2, R4.1
ROW0: D1.1 (K), D2.1 (K), D3.1 (K), D4.1 (K), D5.1 (K), D6.1 (K), U1.15 (PB0)
ROW1: D7.1 (K), D8.1 (K), D9.1 (K), D10.1 (K), D11.1 (K), D12.1 (K), U1.16 (PB1)
ROW2: D13.1 (K), D14.1 (K), D15.1 (K), D16.1 (K), D17.1 (K), D18.1 (K), U1.17 (PB2)
ROW3: D19.1 (K), D20.1 (K), D21.1 (K), D22.1 (K), D23.1 (K), D24.1 (K), U1.18 (PA8)
ROW4: D25.1 (K), D26.1 (K), D27.1 (K), D28.1 (K), D29.1 (K), U1.19 (PA9/UCPD1_DBCC1)
VBUS: F1.1, F2.1, J1.A4 (VBUS), J1.A9 (VBUS), J1.B4 (VBUS), J1.B9 (VBUS), J2.A4 (VBUS), J2.A9 (VBUS), J2.B4 (VBUS), J2.B9 (VBUS), R7.1, R8.1

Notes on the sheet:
RESET button (Tap to reset)
USB-C 2.0 Port - Interconnect
Pull BOOT0 high while reseting to activate DFU.
Notes: FT = 5v tolerant _f = I/O, Fm+ capable _a = I/O, with analog switch function For STM32G0B1, the two UCPD CC pins are: PA8 (UCPD1_CC1) PB15 (UCPD1_CC2) Disable UCPD1 pull-downs to make these pins work as normal GPIOs
Power Regulation
ESD, reverse polarity, and over-current protection
NRST has internal pull-up. Capacitor holds signal stable. Optionally, remove the button, and reset by power-cycling the board.
USB-C 2.0 Port 5.1k resistors to GND on both CC pins indicate that this device is acting in legacy 2.0 UFP mode.
Power Flags
I2C1_SCL/USART1_TX/FT_fa
VDD
~10k resistor approximated with two 5.1k's from USB for BOM reduction
I2C1_SDA/USART1_RX/FT_fa
Decoupling Capacitors
DFU Mode Select (Hold while resetting to enter DFU mode)
Matrix

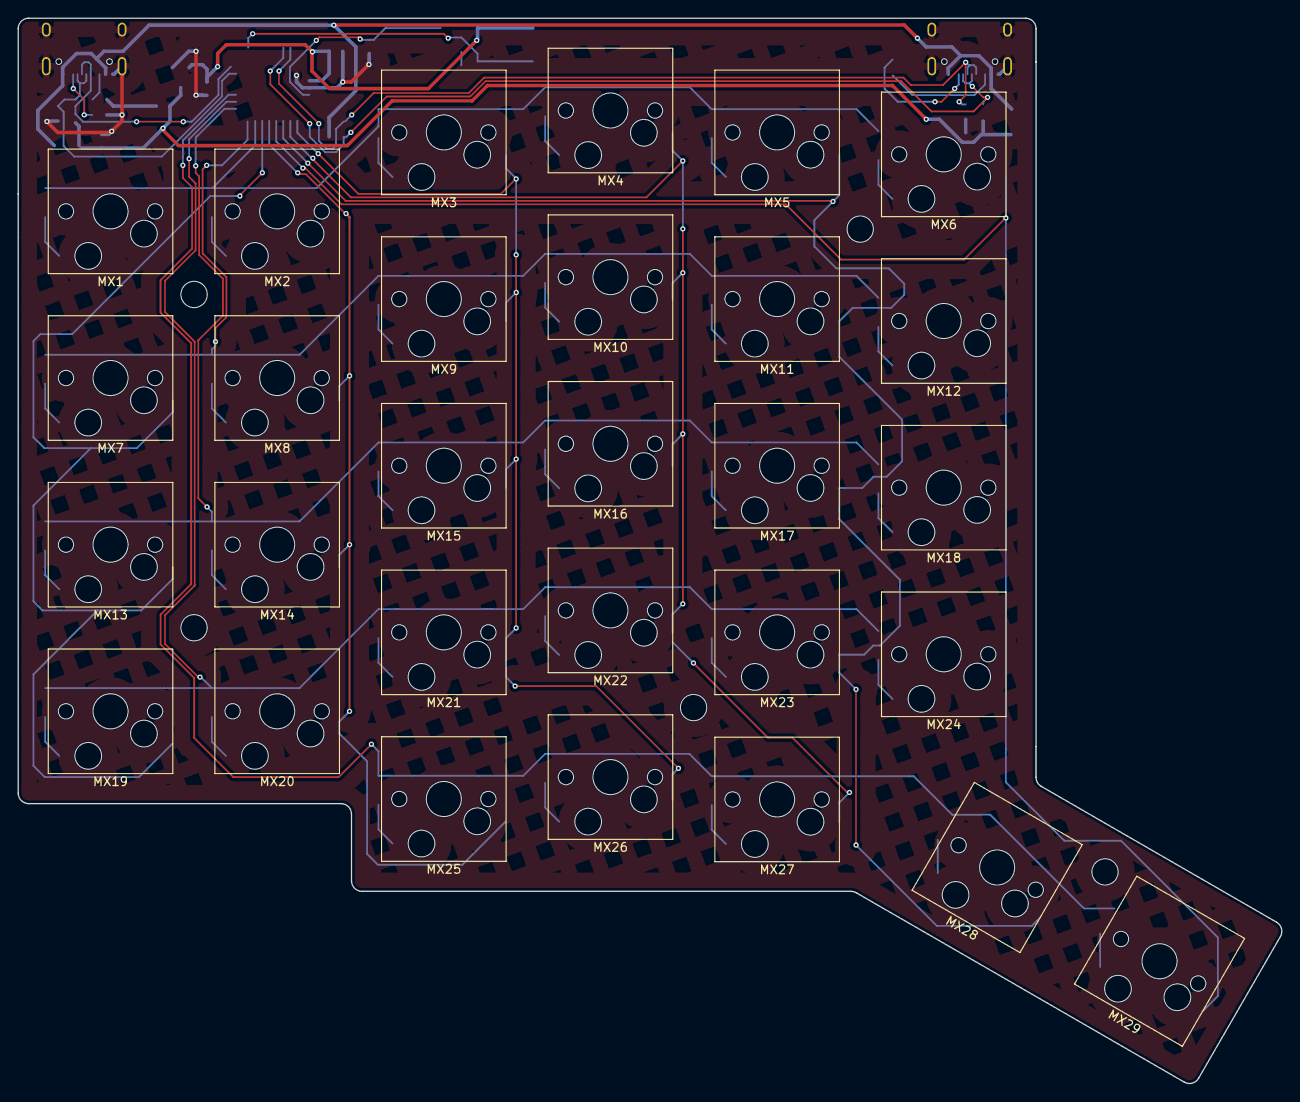
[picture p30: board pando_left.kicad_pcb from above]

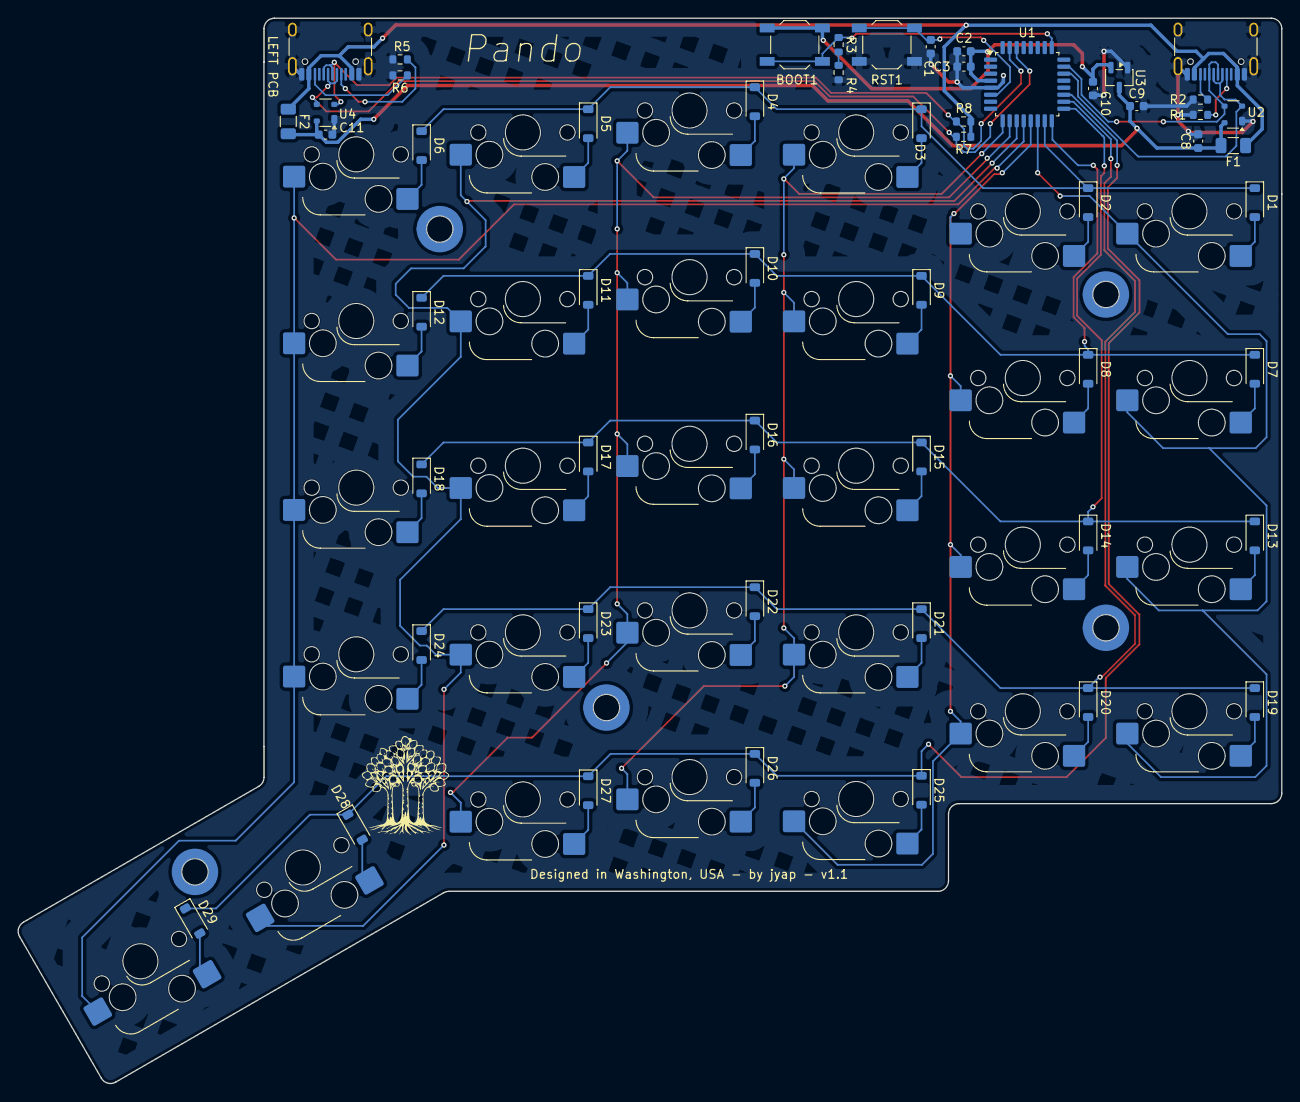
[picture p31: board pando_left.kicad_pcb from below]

Board: 2 copper layers, 144.1 x 121.5 mm, 89 parts (60 on the bottom side), 55 nets.

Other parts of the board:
H1, H2, H3, H4, H5: Mounting_Wuerth_WA-SMSI-M2_H3.5mm_9774035243
Logo1: Pando logo

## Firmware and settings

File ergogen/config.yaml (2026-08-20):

# SPDX-FileCopyrightText: 2026 Julian Yap
# SPDX-License-Identifier: CERN-OHL-S-2.0+

meta:
  engine: 4.1.0
  name: Pando
  author: Julian Yap
  github: jyap808
  version: v1.1.0
  footer_text: &footer_text "Designed in Washington, USA - by jyap - v1.1"

units:
  # Proxy Spacing Variables
  kx: U
  ky: U
  # Padding Variables
  px: kx + 2
  py: ky + 2
  # Defaults to M2 Screws
  screwSize: 1.1
  baseFillet: 1.2
  switchFillet: 0.5

  csWall: 3                # Wall thickness
  csWallThin: 2.8
  csMargin: 0.5            # PCB clearance. 0.5mm for FDM, 0.3mm for MJF are safe margins.
  csMarginThin: 0.3

points:
  zones:
    matrix:
      key:
        tags: ['key']
      # Fix placement on KiCAD sheet.
      anchor:
        shift: [70, -190]
      columns:
        # Sofle v2/RGBv3 aggressive pinky stagger based
        outer:
          key.column_net: COL0
          rows.mod.skip: true
        pinky:
          key.column_net: COL1
          rows.mod.skip: true
        ring:
          key:
            stagger: 9
            column_net: COL2
          rows.mod.column_net: COL1
        middle:
          key:
            stagger: 2.5
            column_net: COL3
          rows.mod.column_net: COL2
        index:
          key:
            stagger: -2.5
            column_net: COL4
          rows.mod:
            skip: true
            column_net: COL3
          #rows.mod.skip: true
          #rows.mod.column_net: COL3
        inner:
          key:
            stagger: -2.5
            column_net: COL5
          rows.mod.skip: true
      rows:
        # Four main rows, one partial row.
        # Ergogen uses Cartesian Coordinates as opposed to a keyboard matrix
        mod:
          row_net: ROW4
        bottom:
          row_net: ROW3
        home:
          row_net: ROW2
        top:
          row_net: ROW1
        num:
          row_net: ROW0
    thumbs:
      key:
        tags: ['key']
      anchor:
        ref: matrix_index_bottom
        shift: [0, -1U]
      columns:
        top:
          key:
            column_net: COL3
        middle:
          key:
            width: 1.25U
            origin: [-0.6U, -0.8U]
            splay: -30
            column_net: COL4
        bottom:
          key:
            # (1.25+1)/2 - 1 = 0.125
            shift: [0.125U, 0]
            column_net: COL5
      rows:
        cluster:
          row_net: ROW4
    # Mounts - Inner
    mount_inner_top_left:
      anchor:
        ref: matrix_outer_top
        shift: [0.5kx, 0.5ky]
    mount_inner_bottom_left:
      anchor:
        ref: matrix_outer_bottom
        shift: [0.5kx, 0.5ky]
    mount_inner_top_right:
      anchor:
        ref: matrix_inner_top
        shift: [-0.5kx, 0.55ky]
    mount_inner_bottom_middle:
      anchor:
        ref: thumbs_top_cluster
        shift: [-0.5kx, 0.55ky]
    mount_inner_bottom_right:
      anchor:
        ref: thumbs_bottom_cluster
        shift: [-0.55kx, 0.3ky]
  mirror: &mirror
    ref: matrix_inner_num
    distance: 5kx

outlines:
  # outline with no padding
  _raw:
    - what: rectangle
      where: /key/
      size: [U,U]
    - what: polygon
      points:
        - ref: thumbs_top_cluster
          shift: [-0.5U, 0.5U]
        - ref: thumbs_top_cluster
          shift: [-0.5U, -0.5U]
        - ref: thumbs_top_cluster
          shift: [1U, -0.5U]
        - ref: thumbs_top_cluster
          shift: [1U, 0.5U]
    - what: polygon
      points:
        # Extend Down
        - ref: matrix_inner_bottom
          shift: [-0.5U, 0.5U]
        - ref: matrix_inner_bottom
          shift: [-0.5U, -1U]
        - ref: matrix_inner_bottom
          shift: [0.5U, -1U]
        - ref: matrix_inner_bottom
          shift: [0.5U, 0.5U]
    - what: polygon
      points:
        # Extend Left
        - ref: thumbs_middle_cluster
          shift: [-1U, 0.5U]
        - ref: thumbs_middle_cluster
          shift: [-1U, -0.5U]
        - ref: thumbs_middle_cluster
          shift: [1U, -0.5U]
        - ref: thumbs_middle_cluster
          shift: [1U, 0.5U]
      fillet: baseFillet
  keys:
    - what: rectangle
      where: /key/
      size: [14,14]
      fillet: switchFillet
  combo_print:
    # Used for printing out and testing layout
    - name: _raw
    - operation: subtract
      name: keys

  _matrix_area_right:
    $extends: outlines._matrix_area_left
    $args: ["mirror_"]
  _matrix_area_left:
    $params: [<mirror>]
    $args: [""]
    area:
      what: rectangle
      where:
        - [/^<mirror>matrix_.*/]
      size: [px, py]
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

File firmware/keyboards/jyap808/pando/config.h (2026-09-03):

// Copyright 2026 Julian Yap (@jyap808)
// SPDX-License-Identifier: GPL-2.0-or-later

#pragma once

#define MATRIX_ROWS  5
#define MATRIX_COLS  12
#define MATRIX_ROWS_PER_SIDE MATRIX_ROWS
#define MATRIX_COLS_PER_SIDE (MATRIX_COLS / 2)

#define MATRIX_ROW_PINS_L { B0, B1, B2, A8, A9 }
#define MATRIX_COL_PINS_L { A7, A6, A2, A3, A4, A5 }

#define MATRIX_ROW_PINS_R { 0b00000001, 0b00000010, 0b00000100, 0b00001000, 0b00010000 }
#define MATRIX_COL_PINS_R { 0b00000001, 0b00000010, 0b00000100, 0b00001000, 0b00010000, 0b00100000 }

// RIGHT_HALF PCA9555 address (A0=A1=A2=GND → 7-bit 0x20)
#define RIGHT_HALF 0x20

#define RIGHT_COLS_PORT PCA9555_PORT0
#define RIGHT_ROWS_PORT PCA9555_PORT1

// I2C for STM32G0B1KBT6 (I2C1 on PB6/PB7 = AF6)
#define I2C_DRIVER I2CD1
#define I2C1_SCL_PIN B6
#define I2C1_SDA_PIN B7
#define I2C1_SCL_PAL_MODE 6
#define I2C1_SDA_PAL_MODE 6

// I2C timing for STM32G0B1 (I2C1 clock = PCLK = 64MHz, ~400kHz Fast mode)
// f_SCL = 64MHz / ((SCLL+1 + SCLH+1) * (PRESC+1))
// PRESC=0, SCLH=38, SCLL=129 → (39+130) = 169 clocks → 378kHz
// SCLDEL=7 → (7+1) x 15.625ns = 125ns data setup (meets FM 100ns minimum)
#define I2C1_TIMINGR_PRESC  0x00U
#define I2C1_TIMINGR_SCLDEL 0x07U
#define I2C1_TIMINGR_SDADEL 0x00U
#define I2C1_TIMINGR_SCLH   0x26U  // 38
#define I2C1_TIMINGR_SCLL   0x81U  // 129

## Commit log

2026-06-11 Plate outline fix
2026-06-11 Rename stm32_poc to pando, add pando_plate PCB
2026-06-11 Place Button switch footprints
2026-06-11 Place MCU and Resistor footprints
2026-06-12 Place more footprints. Minor fixes.
    [config.yaml]
2026-06-12 Add capacitor placeholders
2026-06-12 Add placeholder footprint module
2026-06-13 Add logo footprint, text labels, and SVG gen script
2026-06-16 Add inner mounting hole points and plated footprints
2026-06-16 feat: add KiCad design files for pando split keyboard
    Left and right PCB schematics, layouts, plate design, mounting hole footprint and BOM files
    [pando_left.kicad_pcb, pando_left.kicad_sch, pando_plate.kicad_pcb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]
2026-06-18 feat: add case outlines, sandwich mounts and KiCad fp-lib-tables
2026-06-19 Remove Logo from interactive BOM
2026-07-02 Remove unused/deprecated custom footprint and fp-lib-tables
2026-07-03 v1.1.0: Fix I2C pull-up routing and clean up traces
    - Reposition I2C pull-up resistors R7/R8 with VBUS connections
    - Clean up DATA0/DATA1 label positions and wire routing
    [pando_left.kicad_pcb, pando_left.kicad_sch, pando_right.kicad_pcb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]
2026-07-06 Stop tracking .kicad_prl temp files
2026-07-06 Add KiCad temp and backup files to .gitignore
2026-07-12 Update left PCB and schematic for STM32G0B1CBT6
    Replace STM32F072CBT6 with STM32G0B1CBT6 MCU. Update routing
    and schematics to match new pinout and requirements.
    [pando_left.kicad_pcb, pando_left.kicad_sch]
2026-07-13 Update left PCB and schematic for STM32G0B1KBT6
    Replace STM32G0B1CBT6 with STM32G0B1KBT6 MCU. Update routing
    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
    [pando_left.kicad_pcb, pando_left.kicad_sch]
2026-08-11 regenerate interactive BOM for updated PCB
2026-08-11 ergogen: convert matrix and thumb area outlines to hidden outlines add bottom_weight outline and tweak csWall and csMargin case settings
2026-08-11 ergogen: consolidate pcb_base and plate_base into base_outline
    Merge the identical pcb_base_left and plate_base_left outlines into
    a single base_outline and drop the unused expanded plate outline
2026-08-13 ergogen: remove sandwich case outlines, add MJF case outlines
    Drop the sandwich case (case_sw_outer, _mounts_sw) along with its
    mount points and units. Add new MJF brutalist case outlines
    (case_outer_mjf, case_inner_mjf) with thinner walls and beveled joints.
2026-08-20 ergogen: bump csMargin to 0.5mm to account for ASA/ABS shrinkage
2026-08-28 docs: add Zensical docs framework and firmware/configuration pages
    Set up documentation using Zensical with GitHub Pages deploy workflow,
    devenv integration, and firmware configuration/installing pages.
2026-09-01 case: add FreeCAD case model
    [PandoCase.FCStd]
2026-09-01 chore: ignore kicad production output and FreeCAD backups docs: fix firmware path and use admonition syntax
2026-09-04 kicad: fix footprint models to .stpZ Linux extensions, switch USB-C to KICAD10_3RD_PARTY path
    [pando_left.kicad_pcb, pando_right.kicad_pcb]
2026-09-04 docs: update main case image
2026-09-07 docs: add Gallery page with MJF and 3D printed case examples
2026-09-19 firmware: add cold-boot reset for Mac M3/M4 silicon USB-C workaround
    - Bump device_version to 1.2.0
    [matrix.c]
2026-09-19 docs: add notes for Etsy pre-built boards and pre-configured boot mode
